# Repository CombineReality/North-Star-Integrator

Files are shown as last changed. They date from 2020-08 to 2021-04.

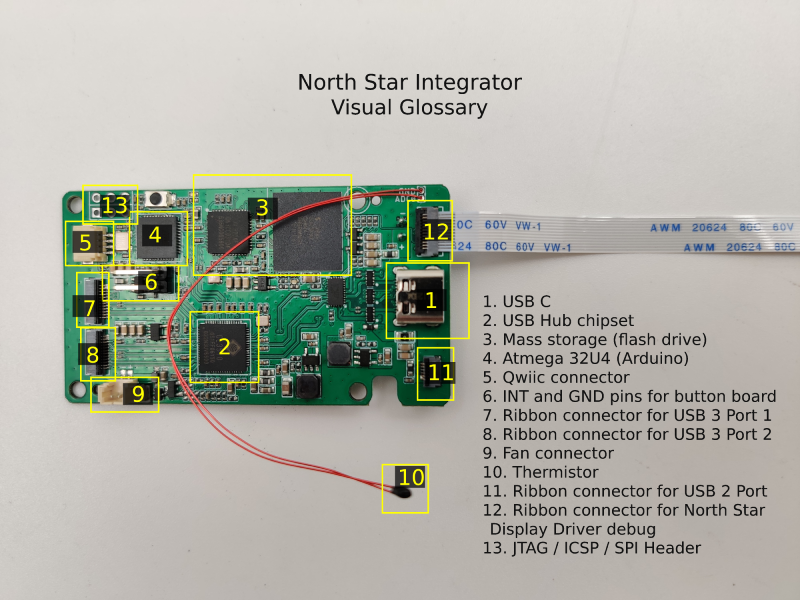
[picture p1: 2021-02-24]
docs/pcb_sections.png

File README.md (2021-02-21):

The Integrator is our custom-built USB hub system originally created for the CombineReality Project North Star Deck X. The Integrator cuts down the use of cables and adds customizable buttons to the headset with the following components & features:

    USB-C hub, two USB 3.1 ribbon connectors, and one USB 2.0 ribbon connector
    3GB on-board flash drive (only works when connected to a USB 3.0 host)
    Arduino-compatible microcontroller, featuring a Qwiic connector that can be used to connect additional sensors like an IMU, as well as HID buttons that can emulate keyboard    keys. A button breakout board is included, and the microcontroller is preflashed with firmware that maps the buttons to the default ergonomics adjustment keys. (Eye relief, eye position, and IPD)
    Also allows for manual power reset of sensor USB ports via a GPIO pin.
    A fan, the speed of which is controlled by the Arduino-compatible microcontroller.
    A thermistor for a more intelligent fan speed control
    A ribbon connector that lets the Arduino on the hub relay commands and debug output to and from the serial UART of the display driver board
    Ribbon adapter board for Intel® RealSense™ T261 embedded 6-DOF module (ribbon cable included)
    Ribbon adapter board for Leap Motion Controller (ribbon cable included)
    
Uses a modified version of the lilyPadUSB-caterina Arduino bootloader
Bootloader can be found here: https://github.com/CombineReality/ArduinoCore-avr

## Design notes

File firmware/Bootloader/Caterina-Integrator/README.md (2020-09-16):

# Arduino_USB_Bootloader
1. git clone 
2. sudo apt-get install gcc-avr binutils-avr gdb-avr avr-libc avrdude
3. cd ../bootloaders/caterina-LilyPadUSB
4. edit the code and makefile if necessary
5. make clean
6. make 
7. file the new HEX file of "Caterina.hex"

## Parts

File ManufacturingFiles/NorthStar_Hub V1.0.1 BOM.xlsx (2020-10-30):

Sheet: PCB SPECS (please fill in)
PCB
File Name/文件名 | Material/板材 | Layer/层数 | Dimension(mm)/尺寸 |  | Quantity/数量 | Separated Different Design/同个Gerber几款板子 | Panelized PCBs/是否拼版 | Solder Mask Color/阻焊颜色 | Silkscreen Color/丝印颜色 | PCB Thickness/板子厚度 | Copper Thickness/外层铜厚 | Inner Copper Thickness/内层铜厚 | Surface Finish/表面处理
 |  |  | X | Y |  |  |  |  |  | (mm) | (oz) | (oz)
NorthStar_Hub V1.0.1 Gerber.zip | FR-4 TG130 | 4 | 67 | 37 | 100 | 1 | Not Required | Green | White | 1 | 1 oz | 0.5 oz | HASL (Hot Air Surface Leveling)
SPECIAL REQUIREMENTS
Min. Tracking/Spacing/最小间距 | 4 mil
Min. Hole Size/最小孔径 | 0.20 mm
BGA/是否有BGA | Yes
Edge Connector/金手指 | No
Blind Vias/盲孔 | No
Half Cutted Holes/半孔 | No
Impedance Control/阻抗 | Yes | 嘉立创 JLC2313层压结构
STENCIL
Stencil Dimensions/钢网大小 | 140 x 240 mm (with frame)
Stencil Quantity/数量 | 1
Fiducial Mark/马克点 | Yes
Polishing Technique/钢网类型 | Polishing
REMARK
Please leave comment here if you have special requirements./特殊要求请备注
Our Smart-Prototyping website is for your reference. (http://smart-prototyping.com/PCB-Prototyping.html)

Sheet: BOM (please fill in)
Project Name (Required)/项目名字 |  | NorthStar
# | Part ID / Reference (Required)/位号 | Manufacturer/品牌 | Part Number (Required)/物料型号 | Description/物料描述 | Value (Required)/物料数值 | Package (Required)/物料封装 | THT (y/n)/直插为y，贴片为n | Pins / Pads Qty/管脚数量 | Quantity per BOM (Required)/用量
1 | C1, C21 | SAMSUNG | CL05C200JB5NNNC |  | 20pF ±5% 50V | C0402 |  |  | 2
2 | C25, C30, C71, C75, C78, C81, C82, C89, C99 | SAMSUNG | CL05A105KP5NNNC |  | 1uF ±10% 10V | C0402 |  |  | 9
3 | C3, C4, C5, C6, C7, C8, C15, C16, C41, C42, C43, C48, C69, C70 | SAMSUNG | CL03A104KP3NNNC |  | 100nF ±10% 10V | C0201 |  |  | 14
4 | C9, C56 | SAMSUNG | CL10A475KP8NNNC |  | 4.7uF ±10% 10V | C0603 |  |  | 2
5 | C10, C13, C17, C19, C22, C24, C33, C34, C35, C36, C37, C44, C52, C57, C59, C60, C61, C62, C63, C64, C65, C67, C68, C72, C79, C80, C84, C86, C88, C90, C91, C92, C93, C94, C95, C96, C97, C101, C104, C105, C106 | SAMSUNG | CL05B104KP5NNNC |  | 100nF ±10% 10V | C0402 |  |  | 41
6 | C11, C58 | SAMSUNG | CL05C560JB5NNNC |  | 56pF ±5% 50V | C0402 |  |  | 2
7 | C12, C49, C66, C100, C102, C103 | SAMSUNG | CL10A106MP8NNNC |  | 10uF ±10% 10V | C0603 |  |  | 6
8 | C14, C29 | SAMSUNG | CL21A226MPQNNNE |  | 22uF ±20% 10V | C0805 |  |  | 2
9 | C18, C20, C23, C26, C27, C28, C32, C38, C39, C45, C46, C47, C53, C54, C55 | SAMSUNG | CL10A226MP8NUNE |  | 22uF ±20% 10V | C0603 |  |  | 15
10 | C31, C85 | SAMSUNG | CL05C220JB5NNNC |  | 22pF ±5% 50V | C0402 |  |  | 2
11 | C40, C50, C73, C74, C83, C87, C98 | SAMSUNG | CL05A225MP5NNNC |  | 2.2uF ±10% 10V | C0402 |  |  | 7
12 | C76, C77 | SAMSUNG | CL05C120JB5NNNC |  | 12pF ±10% 50V | C0402 |  |  | 2
13 | D1, D2, D5 | TI | TPD4E05U06DQAR |  | TPD4E05U06DQAR | USON-10_L2.5-W1.0-P0.50-BL |  |  | 3
14 | D3, D6 | EVERLIGHT | 16-213/BHC-AN1P2/3T |  | BLUE | 0402_LED |  |  | 2
15 | D4 | 安森美 | ESD5Z6.0T1G |  | ESD5Z6.0T1G | SOD523 |  |  | 1
16 | H1 | TOSHIBA(东芝) | THGBMNG5D1LBAIL |  | THGBMNG5D1LBAIL | BGA153C50P14X14_11.5X13 |  |  | 1
17 | IC1 | GENESYS(创惟) | GL3510-OSY50 |  | GL3510-OSY50 | QFN40P800X800X80-65N |  |  | 1
18 | IC2 | MICROCHIP | ATMEGA32U4-MUR |  | ATMEGA32U4-MUR | QFN50P700X700X100-45N |  |  | 1
19 | J1 | HRS | FH34SRJ-6S-0.5SH(50) |  | FH34SRJ-6S-0.5SH(50) | FH34RJ-6S |  |  | 1
20 | J3, J8, J9 | HRS | FH34SRJ-12S-0.5SH(50) |  | FH34SRJ-12S-0.5SH(50) | FPC-0.5-12P |  |  | 3
21 | J4 | BOOMELE(博穆精密) | XH-2AW |  | XH-2AW | XH-02-90 |  |  | 1
22 | J6 | JST | SM04B-SRSS-TB(LF)(SN) |  | SM04B-SRSS-TB(LF)(SN) | SM04B-SRSS-TB |  |  | 1
23 | K1 | ALPS | SKRKAEE020 |  | SKRKAEE020 | SKRKAEE020 |  |  | 1
24 | L1, L10 | SXN(顺翔诺) | SMNR4012-2R2MT |  | SMNR4012-2R2MT | L4012 |  |  | 2
25 | L2, L3, L4, L5, L6, L7, L8, L9 | muRata | BLM18EG221SN1D |  | BLM18EG221SN1D | L0603 |  |  | 8
26 | R1, R17, R33, R35, R40, R43, R44, R45 | UNI-ROYAL(厚声) | 0402WGF1002TCE |  | 10K ±1% | R0402 |  |  | 8
27 | R2 | UNI-ROYAL(厚声) | 0402WGF4702TCE |  | 47K ±1% | R0402 |  |  | 1
28 | R3, R26 | UNI-ROYAL(厚声) | 0402WGF1004TCE |  | 1M ±1% | R0402 |  |  | 2
29 | R22 | UNI-ROYAL(厚声) | 0402WGF6800TCE |  | 680R ±1% | R0402 |  |  | 1
30 | R5 | UNI-ROYAL(厚声) | 0805W8F0000T5E |  | 0R ±1% | R0805 |  |  | 1
31 | R6, R9, R36, R39 | UNI-ROYAL(厚声) | 0402WGF1003TCE |  | 100K ±1% | R0402 |  |  | 4
32 | R7, R37 | UNI-ROYAL(厚声) | 0402WGF3604TCE |  | 3.6M ±1% | R0402 |  |  | 2
33 | R12 | UNI-ROYAL(厚声) | 0402WGF4703TCE |  | 470K ±1% | R0402 |  |  | 1
34 | R13 | UNI-ROYAL(厚声) | 0402WGF1073TCE |  | 107K ±1% | R0402 |  |  | 1
35 | R15, R27, R30, R47, R48, R49, R50, R51 | UNI-ROYAL(厚声) | 0402WGF4701TCE |  | 4.7K ±1% | R0402 |  |  | 8
36 | R16, R18, R19 | UNI-ROYAL(厚声) | 0402WGF2003TCE |  | 200K ±1% | R0402 |  |  | 3
37 | R20 | UNI-ROYAL(厚声) | 0402WGF9093TCE |  | 909K ±1% | R0402 |  |  | 1
38 | R21, R38, R41, R42, R46 | UNI-ROYAL(厚声) | 0402WGF0000TCE |  | 0R ±1% | R0402 |  |  | 5
39 | R23, R32 | UNI-ROYAL(厚声) | 0402WGF2001TCE |  | 2K ±1% | R0402 |  |  | 2
40 | R24 | UNI-ROYAL(厚声) | 0402WGF470JTCE |  | 47R ±1% | R0402 |  |  | 1
41 | R25, R34 | UNI-ROYAL(厚声) | 0402WGF5102TCE |  | 51K ±1% | R0402 |  |  | 2
42 | R28, R29 | UNI-ROYAL(厚声) | 0402WGF220JTCE |  | 22R ±1% | R0402 |  |  | 2
43 | R31 | UNI-ROYAL(厚声) | 0402WGF2200TCE |  | 220R ±1% | R0402 |  |  | 1
44 | U2 | TI | HD3SS3220RNHR |  | HD3SS3220RNHR | RNH0030A |  |  | 1
45 | U3 | GENESYS(创惟) | GL3224E-ONY04 |  | GL3224E-ONY04 | TQFN48_7MM |  |  | 1
46 | U4, U5 | 矽力杰silergy | SY8089AAAC |  | SY8089AAAC | SOT23-5 |  |  | 2
47 | U6, U7, U8 | TI | TPS2065CDBVR |  | TPS2065C | SOT23-5 |  |  | 3
48 | USBC1 | MOLEX | 1054500101 |  | 1054500101 | USB-C-SMD_TYPE-C-USB-18 |  |  | 1
49 | X1 | EPSON(爱普生) | X1E000021011900 |  | X1E000021011900 | 4P-SMD-3.2X2.5 |  |  | 1
50 | X3, X4 | EPSON(爱普生) | Q22FA12800388 |  | Q22FA12800388 | 4P-SMD-2X1.6MM |  |  | 2
51 | FPC排线0.5mm 12P 同向 |  |  | FPC软排线 间距 0.5mm 12P 同向A型 8cm |  |  |  |  | 2
52 | FPC排线0.5mm 6P 同向 |  |  | FPC软排线 间距 0.5mm 6P 同向A型 8cm |  |  |  |  | 1
53 | D7 | Nexperia(安世) | PMEG2010EA,115 |  | PMEG2010EA,115 | SOD323 |  |  | 1
54 | J5 | 533980271 | 533980271 |  | MX1.25-2P-90 | MX1.25-2P-90 |  |  | 1
55 | Q1 | CJ江苏长电(授权代理) | CJ2301 S1 |  | CJ2301 S1 | SOT23 |  |  | 1
56 | Q2 | CJ江苏长电(授权代理) | DTC143ZUA |  | DTC143ZUA | SOT323 |  |  | 1
57 | RT1 | 时恒 | MF52B 103F3950-100mm | 绝缘红色漆包引线,线长100mm | MF52B 103F3950-100mm |  |  |  | 1
58 | J7 |  |  | 2.54MM 单排正弯针 1*2P PA6.0 |  | 2P-2.54-65/35MIL
59 | Q3, Q4 | CJ江苏长电(授权代理) | BSS138W |  | BSS138W | SOT-323 |  |  | 2
60 | R4 | UNI-ROYAL(厚声) | 0402WGF2002TCE |  | 20K ±1% | R0402 |  |  | 1

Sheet: BOM Reference
BOM/PCBA quantity (Required) |  | 10
PCB/Project Name (Required) |  | Main Control V1.0
# | Part ID / Reference (Required) | Manufacturer | Part Number (Required) | Description | Value (Required) | Package (Required) | THT (y/n) | Pins / Pads Qty | Quantity per BOM (Required)
1 | C1, C2, C3, C4, C5, C7, C8, C9, C10, C11, C12, C13, C14, C15, C16, C17 | Samsung | CL10B104KB8NNNC | Capacitor SMD Cer 100nF 10% 50V X7R 0603 | 100nF | 0603 | n | 2 | 16
2 | R1, R2 | KOA | RK73H1ETTP1001F | 1KΩ (1001) ±1% |  | 0402 | n | 2 | 2
3 | U1 | MICROCHIP | ATMEGA88PA-AU | IC MCU 8BIT 8KB FLASH 32TQFP |  | 32TQFP | n | 32 | 1
4 | D3, D4, D5 | Kingbright | APT1608SURCK | LED 0603 SMD Hyper Red 630nm 220mcd 20mA |  |  | n | 2 | 4
5 | D1 | Lite-On Inc | LTL-4231N | Trigger LED |  |  | y | 2 | 1

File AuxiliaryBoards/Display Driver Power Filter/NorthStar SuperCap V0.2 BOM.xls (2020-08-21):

# | Part ID/Reference | Manufacturer | Part Number | Description | Value | Package | THT | Pins/Pads Qty | Source/Link/Datasheet/Note | Quantity/per BOM | NOTE
 | C1 | KORCHIP | DCS5R5104 |  | DCS5R5104 | 11.5X5.5MM-P10 H-TYPE |  |  |  | 1 |  | 2.11
 | C2 | Rubycon | 10YXF470MEFCT78X11.5 |  | 10YXF470MEFCT78X11.5 | ELECTRO-8.0MM |  |  |  | 1 |  | 0.334787
 | J2 |  |  | 单排错列蜈蚣脚排母2P 间距2.54 塑高5mm 左前右后 |  | 2P-2.54-BOTTOM-ENTRY |  |  | https://item.taobao.com/item.htm?spm=a1z09.2.0.0.67002e8d9SZdHa&id=548294171308&_u=21o068jo1c38 | 1 |  | 0.5
 | XH-2P 线 |  |  | XH2.54-2P 端子线 单头上锡 5CM 左红右黑 |  |  |  |  | https://item.taobao.com/item.htm?id=551594001350&ns=1&abbucket=12 (https://item.taobao.com/item.htm?spm=a230r.1.14.16.665015daMGJz8G&id=551594001350&ns=1&abbucket=12) | 1

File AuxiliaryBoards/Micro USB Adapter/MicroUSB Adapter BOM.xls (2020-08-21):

# | Part ID/Reference | Manufacturer | Part Number | Description | Value | Package | THT | Pins/Pads Qty | Source/Link/Datasheet/Note | Quantity/per BOM | NOTE
 | J1 | HRS | FH34SRJ-6S-0.5SH(50) |  | FPC-0.5-6P | FH34RJ-6S |  |  |  | 1 |  | 0.37208
 | J2 | 韩国韩荣 | U-G-M5WS-W-01 |  | MICRO_USB_MALEU-G-M5WS-W-01 | U-G-M5WS-W-01 |  |  |  | 1 |  | 0.603

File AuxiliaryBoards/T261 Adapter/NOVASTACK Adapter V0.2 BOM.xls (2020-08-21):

# | Part ID/Reference | Manufacturer | Part Number | Description | Value | Package | THT | Pins/Pads Qty | Source/Link/Datasheet/Note | Quantity/per BOM | NOTE
 | D4 | 安森美 | ESD5Z6.0T1G |  | ESD5Z6.0T1G | SOD523 |  |  |  | 1 |  | 0.183493
 | J1 | HRS | FH34SRJ-12S-0.5SH(50) |  | FPC-0.5-12PFPC-0.5-12P | FPC-0.5-12P |  |  |  | 1 |  | 0.53
 | J2 | I-PEX | 20709-034E-01 |  | 20709-034E-01 | IPEX_20709-034E-01 |  |  |  | 1 | https://item.taobao.com/item.htm?spm=a1z09.2.0.0.7c7c2e8d4lBHUf&id=606906908072&_u=21o068jo1c7e | 5

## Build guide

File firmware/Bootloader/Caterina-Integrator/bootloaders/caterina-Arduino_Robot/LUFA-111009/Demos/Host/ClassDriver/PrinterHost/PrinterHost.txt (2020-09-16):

/** \file
 *
 *  This file contains special DoxyGen information for the generation of the main page and other special
 *  documentation pages. It is not a project source file.
 */

/** \mainpage Printer Host Demo
 *
 *  \section Sec_Compat Demo Compatibility:
 *
 *  The following list indicates what microcontrollers are compatible with this demo.
 *
 *  - Series 7 USB AVRs (AT90USBxxx7)
 *
 *  \section Sec_Info USB Information:
 *
 *  The following table gives a rundown of the USB utilization of this demo.
 *
 *  <table>
 *   <tr>
 *    <td><b>USB Mode:</b></td>
 *    <td>Host</td>
 *   </tr>
 *   <tr>
 *    <td><b>USB Class:</b></td>
 *    <td>Printer Device</td>
 *   </tr>
 *   <tr>
 *    <td><b>USB Subclass:</b></td>
 *    <td>Bidirectional Protocol</td>
 *   </tr>
 *   <tr>
 *    <td><b>Relevant Standards:</b></td>
 *    <td>USBIF Printer Class Specification \n
 *        PCL Language Specification</td>
 *   </tr>
 *   <tr>
 *    <td><b>Usable Speeds:</b></td>
 *    <td>Low Speed Mode \n
 *        Full Speed Mode</td>
 *   </tr>
 *  </table>
 *
 *  \section Sec_Description Project Description:
 *
 *  Printer host demonstration application. This gives a simple reference
 *  application for implementing a USB Printer host, for USB printers using
 *  the bidirectional data encapsulation protocol and PCL language.
 *
 *  Upon connection of a compatible printer, the printer's device ID is sent
 *  to the AVR's serial port, and a simple test page is printed using the PCL
 *  printer language.
 *
 *  \section Sec_Options Project Options
 *
 *  The following defines can be found in this demo, which can control the demo behaviour when defined, or changed in value.
 *
 *  <table>
 *   <tr>
 *    <td>
 *     None
 *    </td>
 *   </tr>
 *  </table>
 */

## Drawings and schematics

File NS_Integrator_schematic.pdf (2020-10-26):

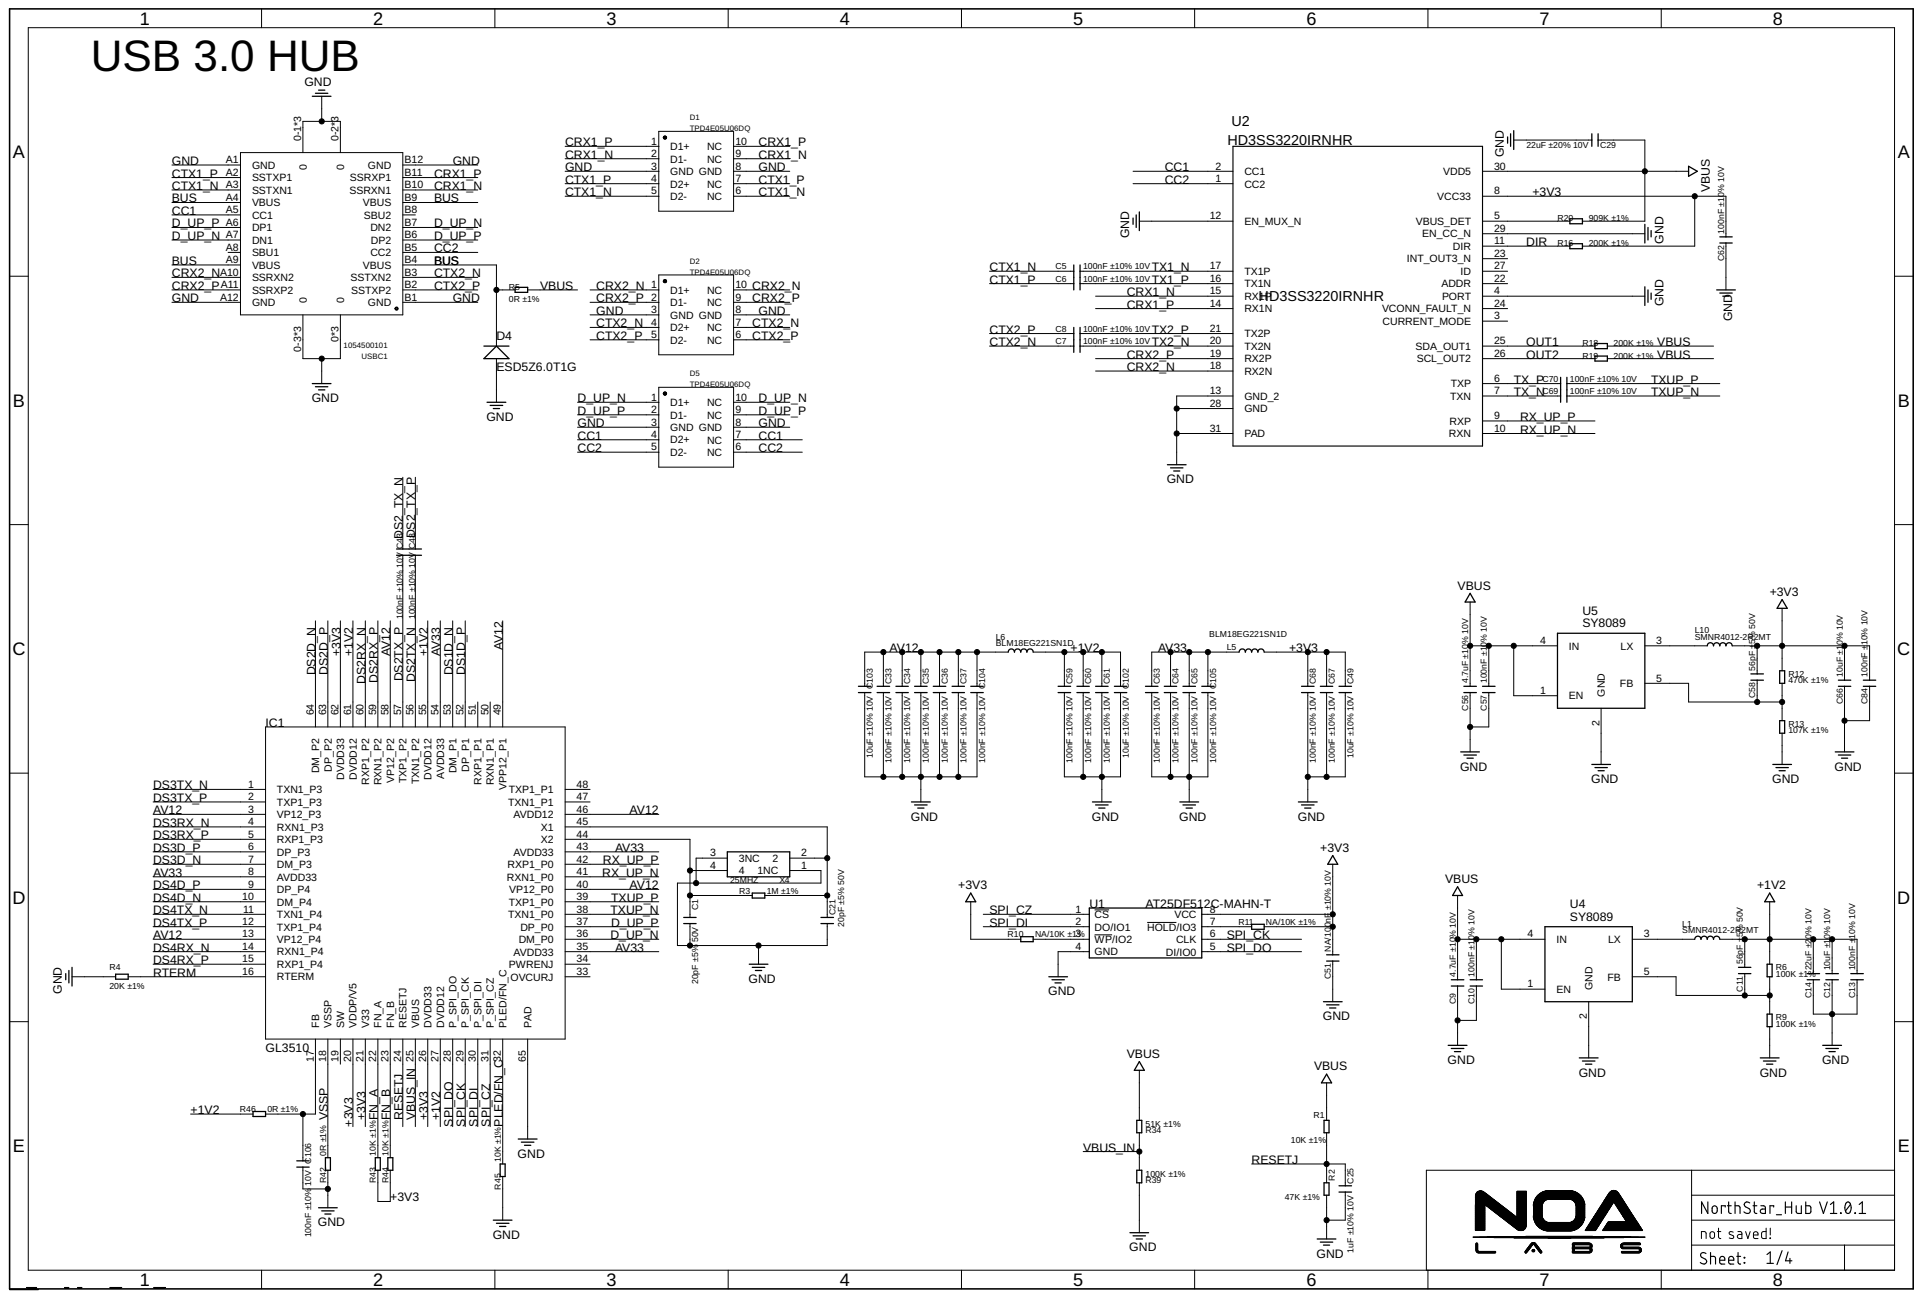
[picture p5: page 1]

39 VP12_P0 TXUP_P | 1M ±1%

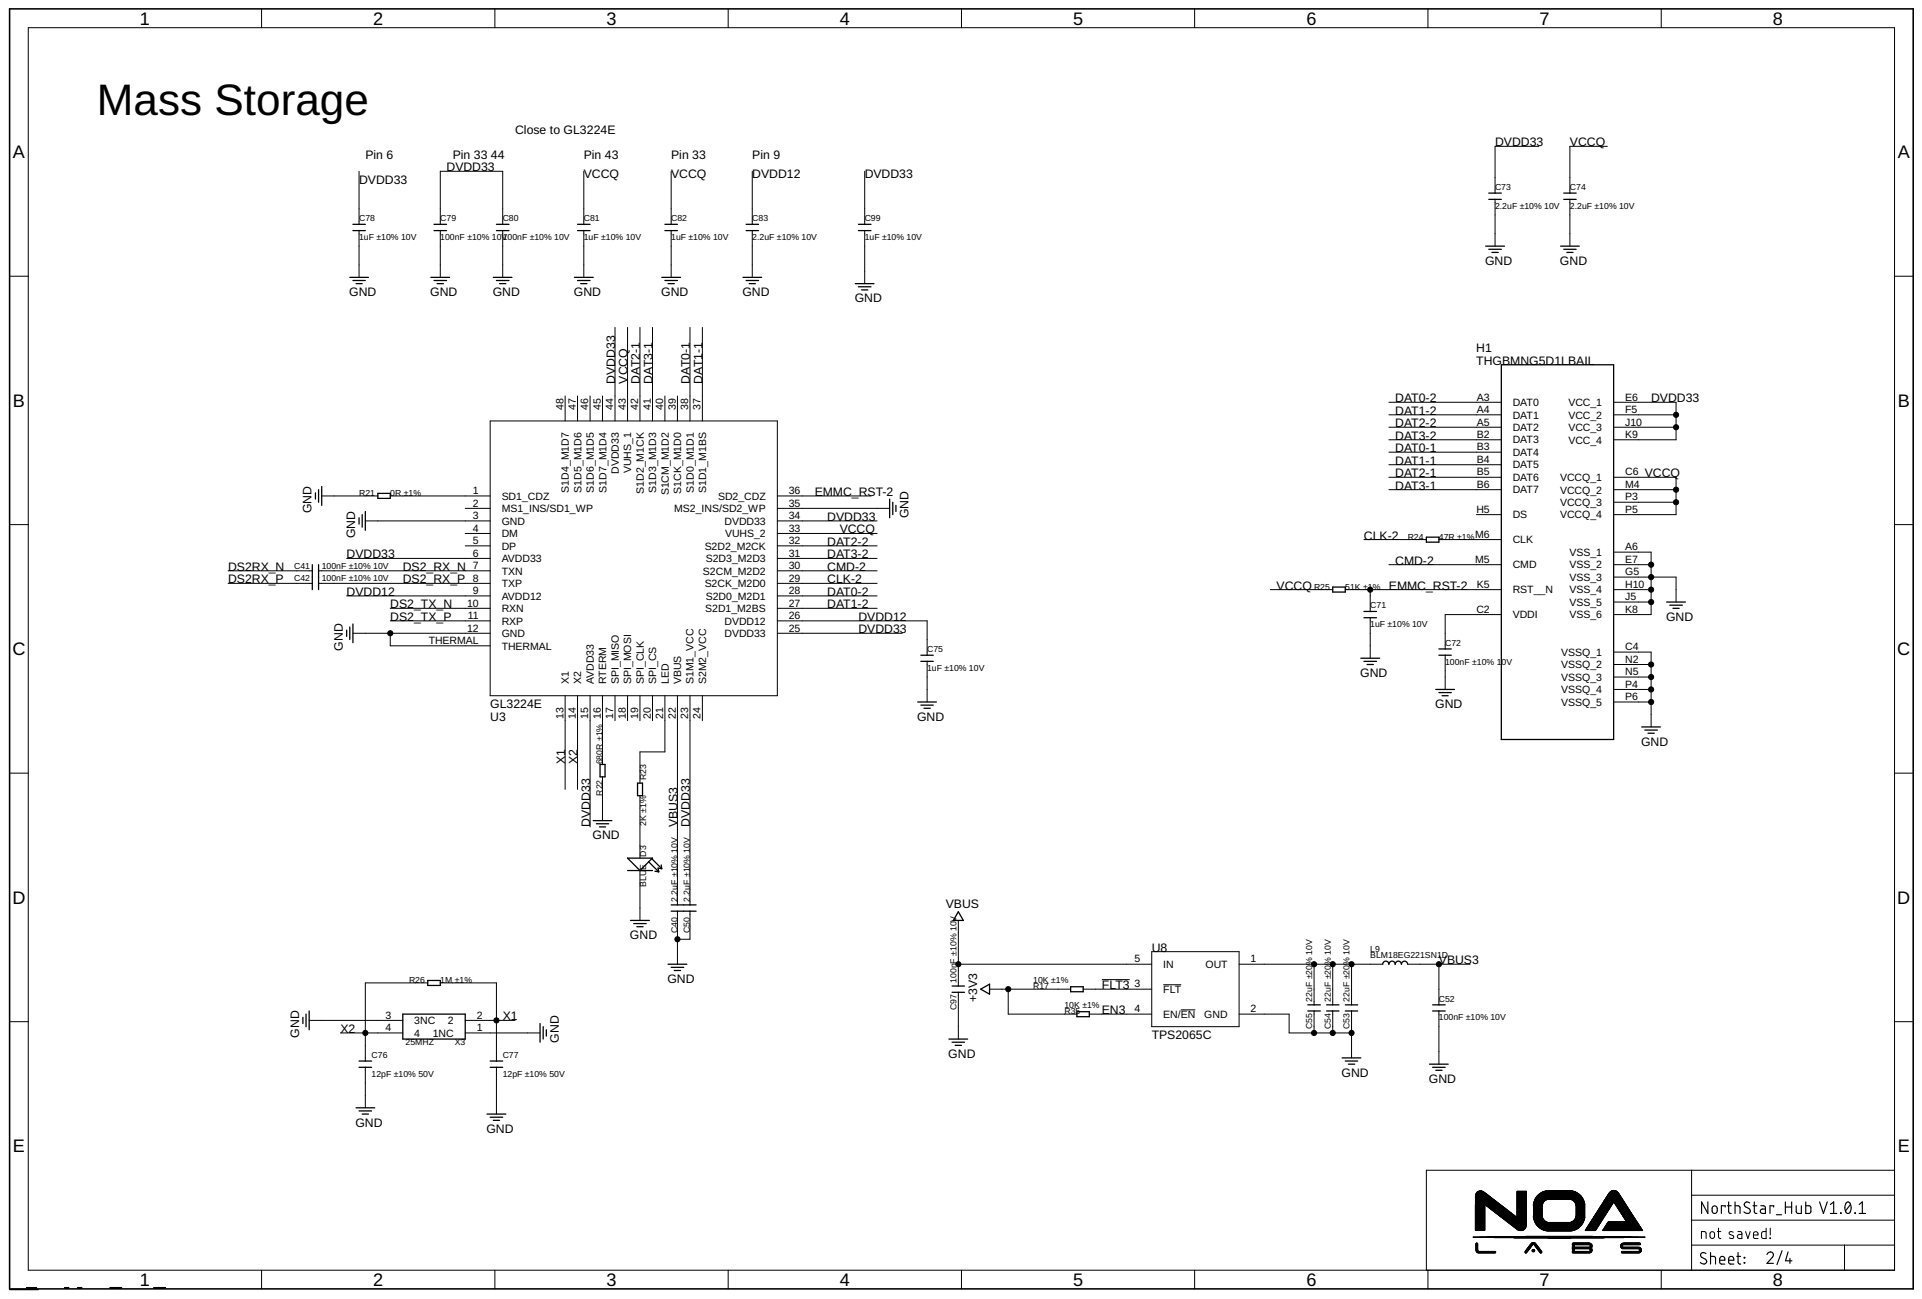
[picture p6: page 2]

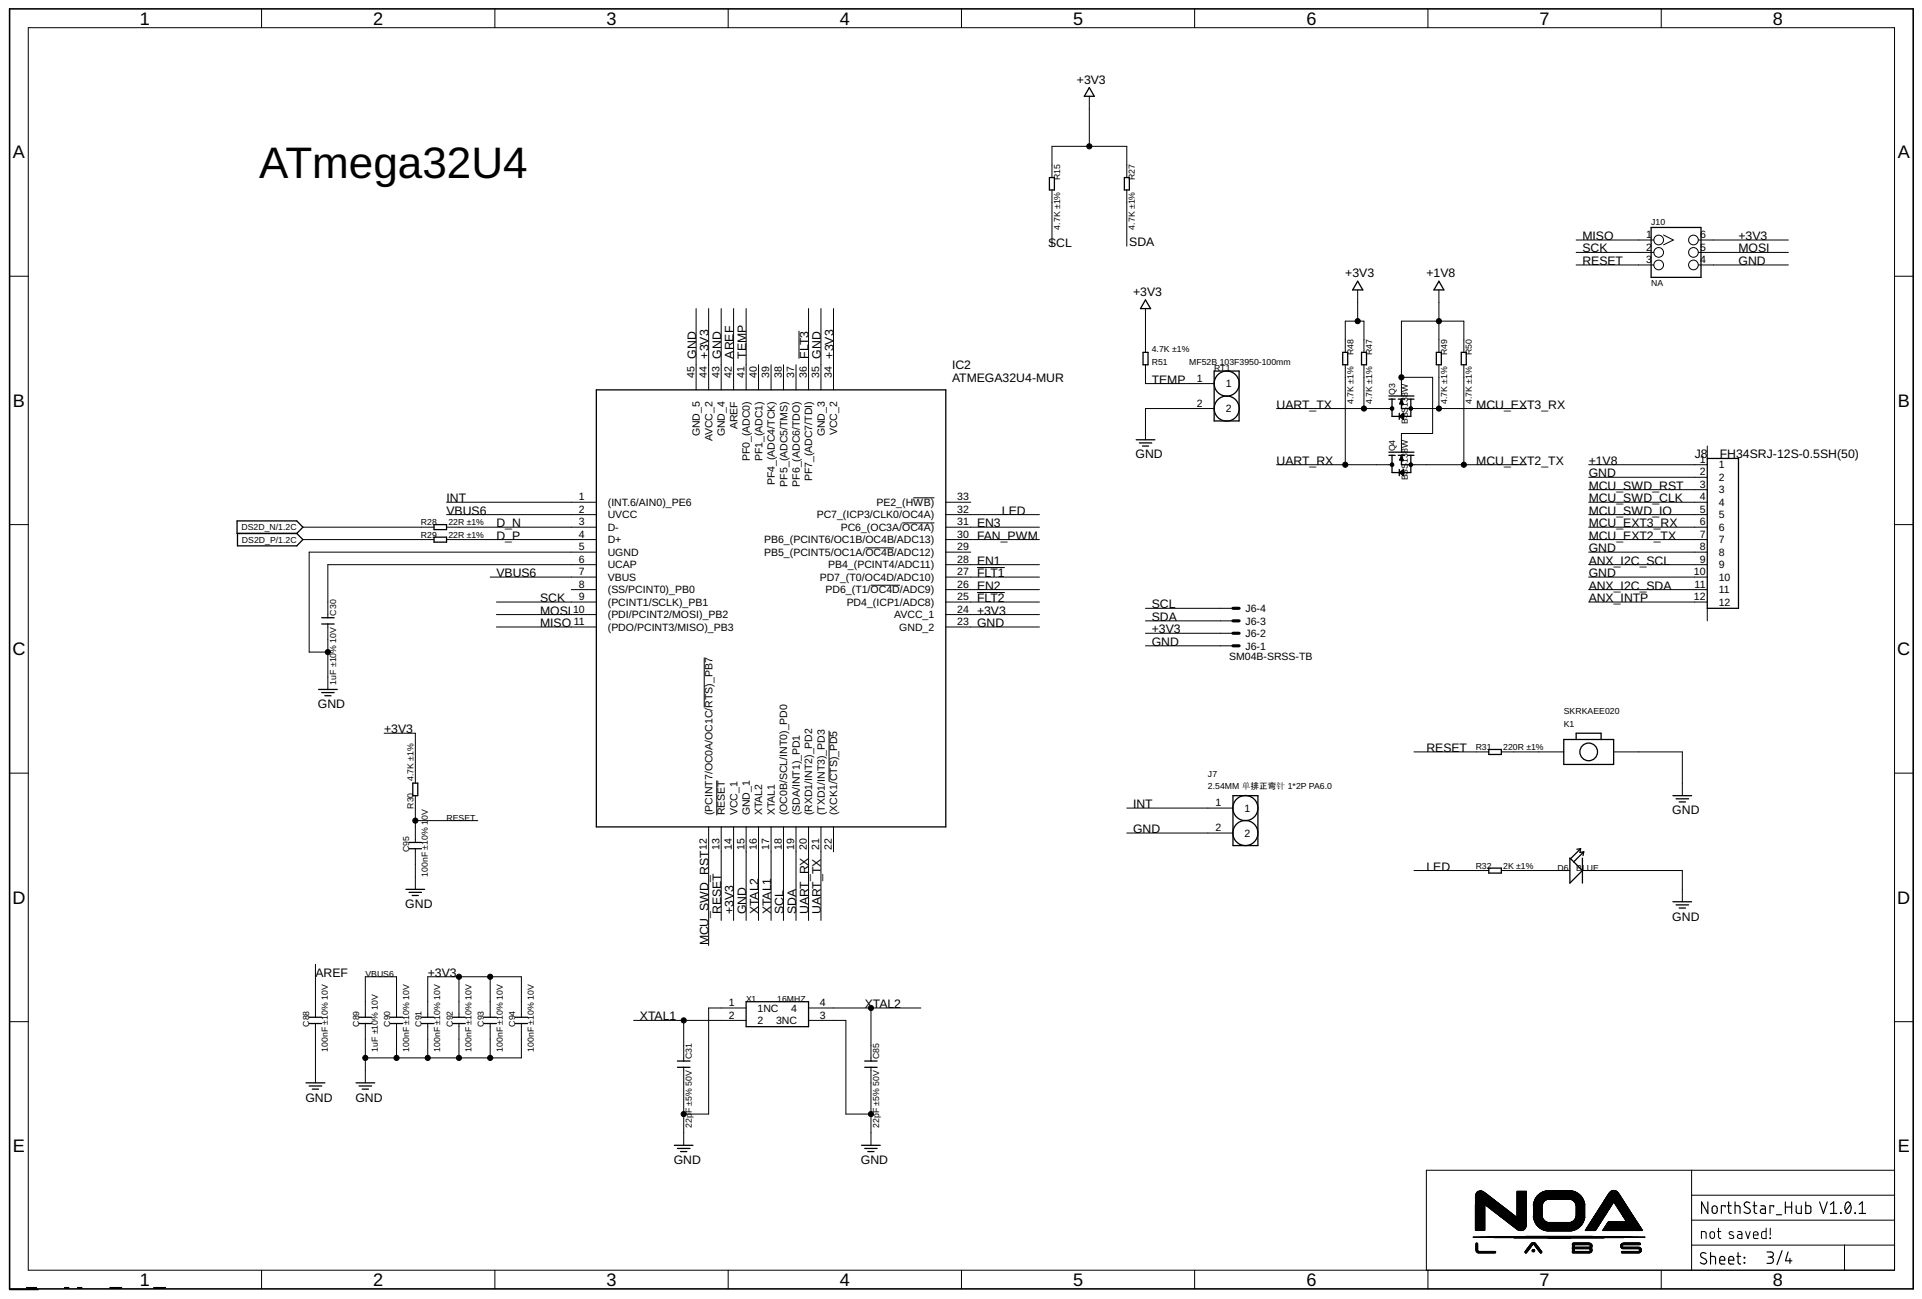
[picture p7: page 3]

GND GND

42 PF0_(ADC0) 41 PF1_(ADC1) 40 PF4_(ADC4/TCK) 39 PF5_(ADC5/TMS) 38 PF6_(ADC6/TDO) 37 PF7_(ADC7/TDI) 36 GND_3

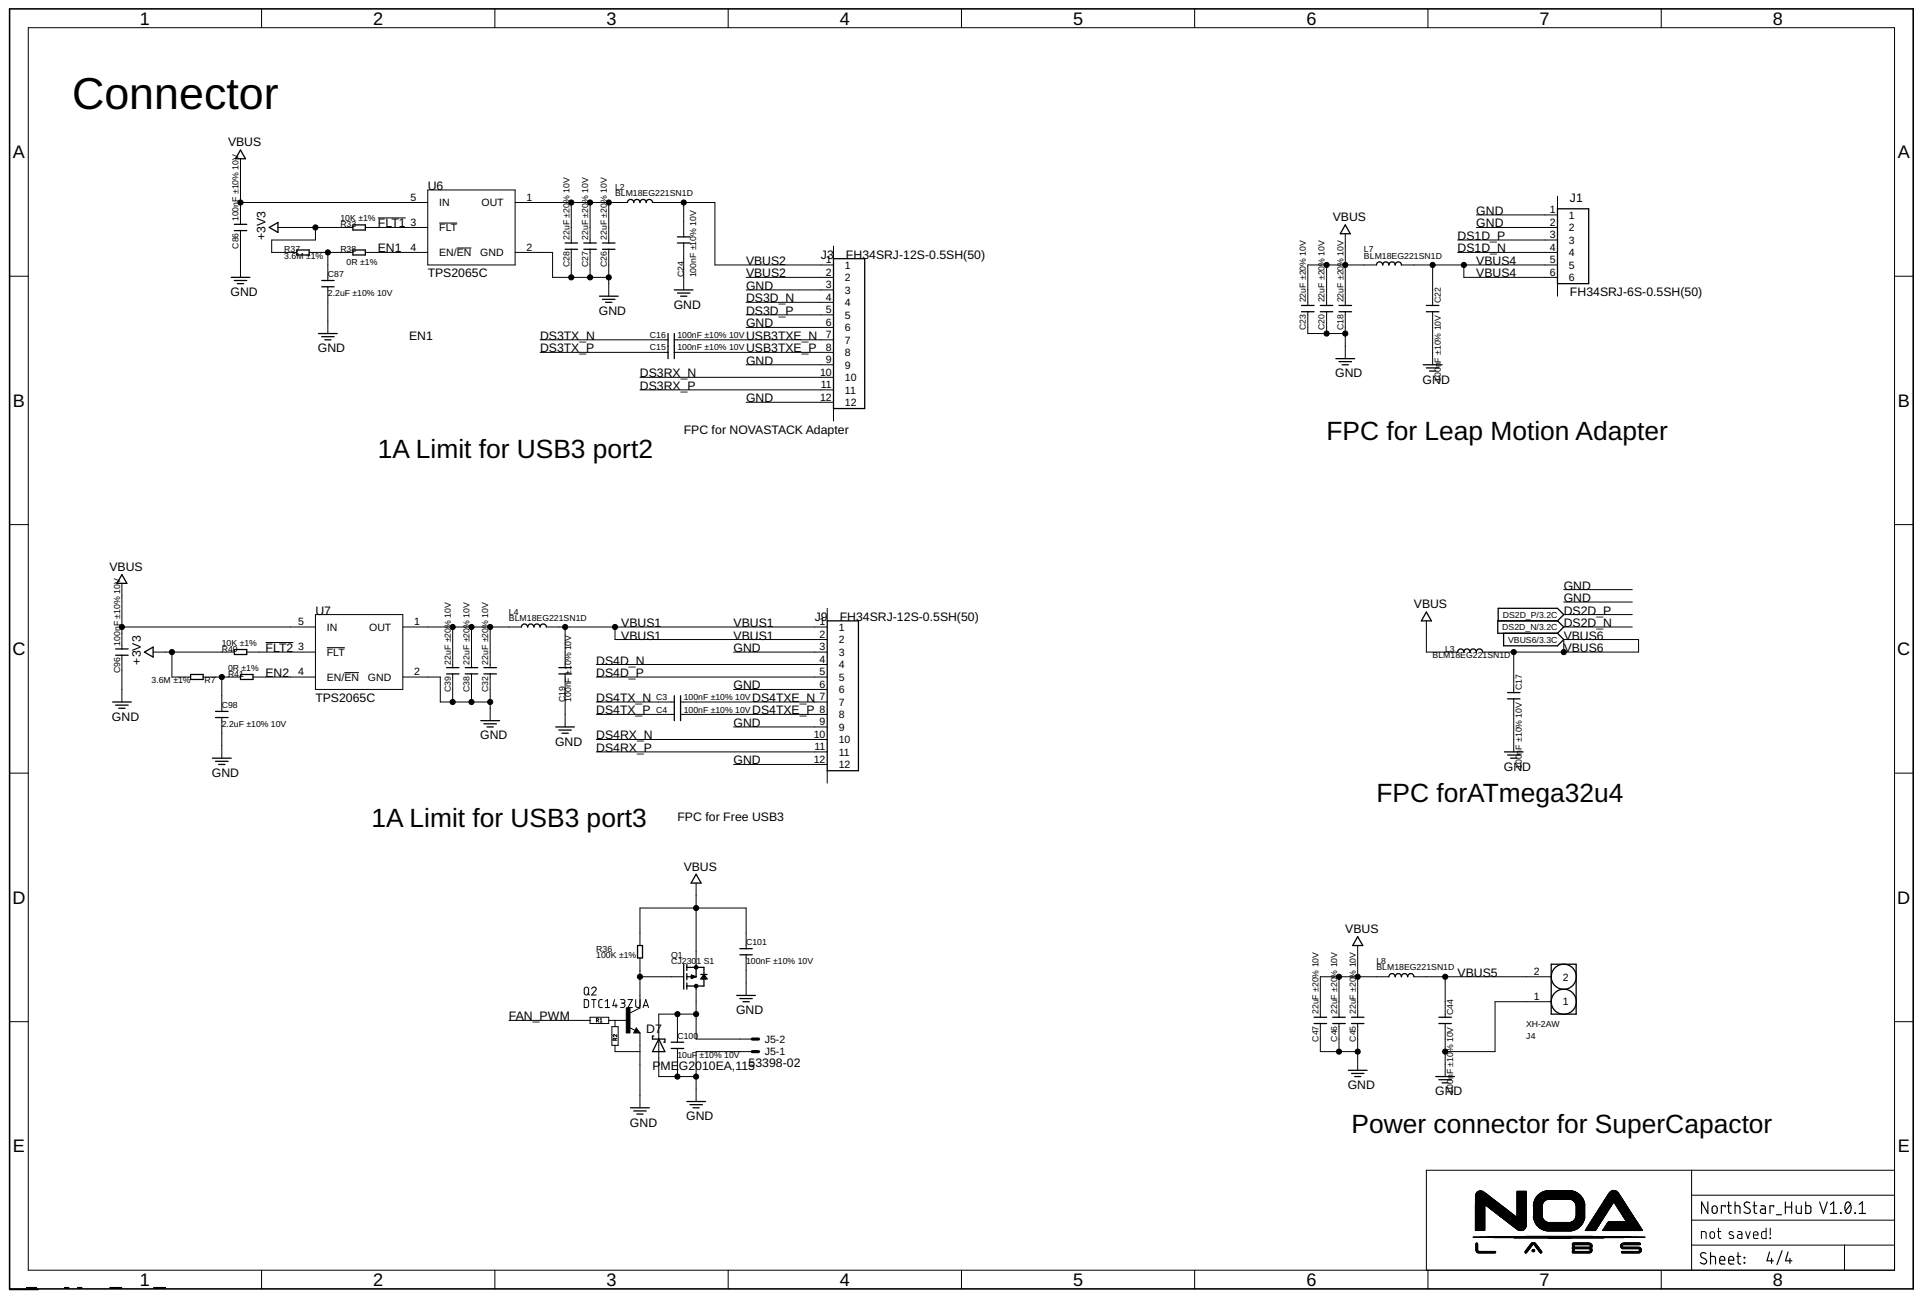
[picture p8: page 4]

FPC for NOVASTACK Adapter

FPC for Leap Motion Adapter

GND GND

GND
Power connector for SuperCapactor

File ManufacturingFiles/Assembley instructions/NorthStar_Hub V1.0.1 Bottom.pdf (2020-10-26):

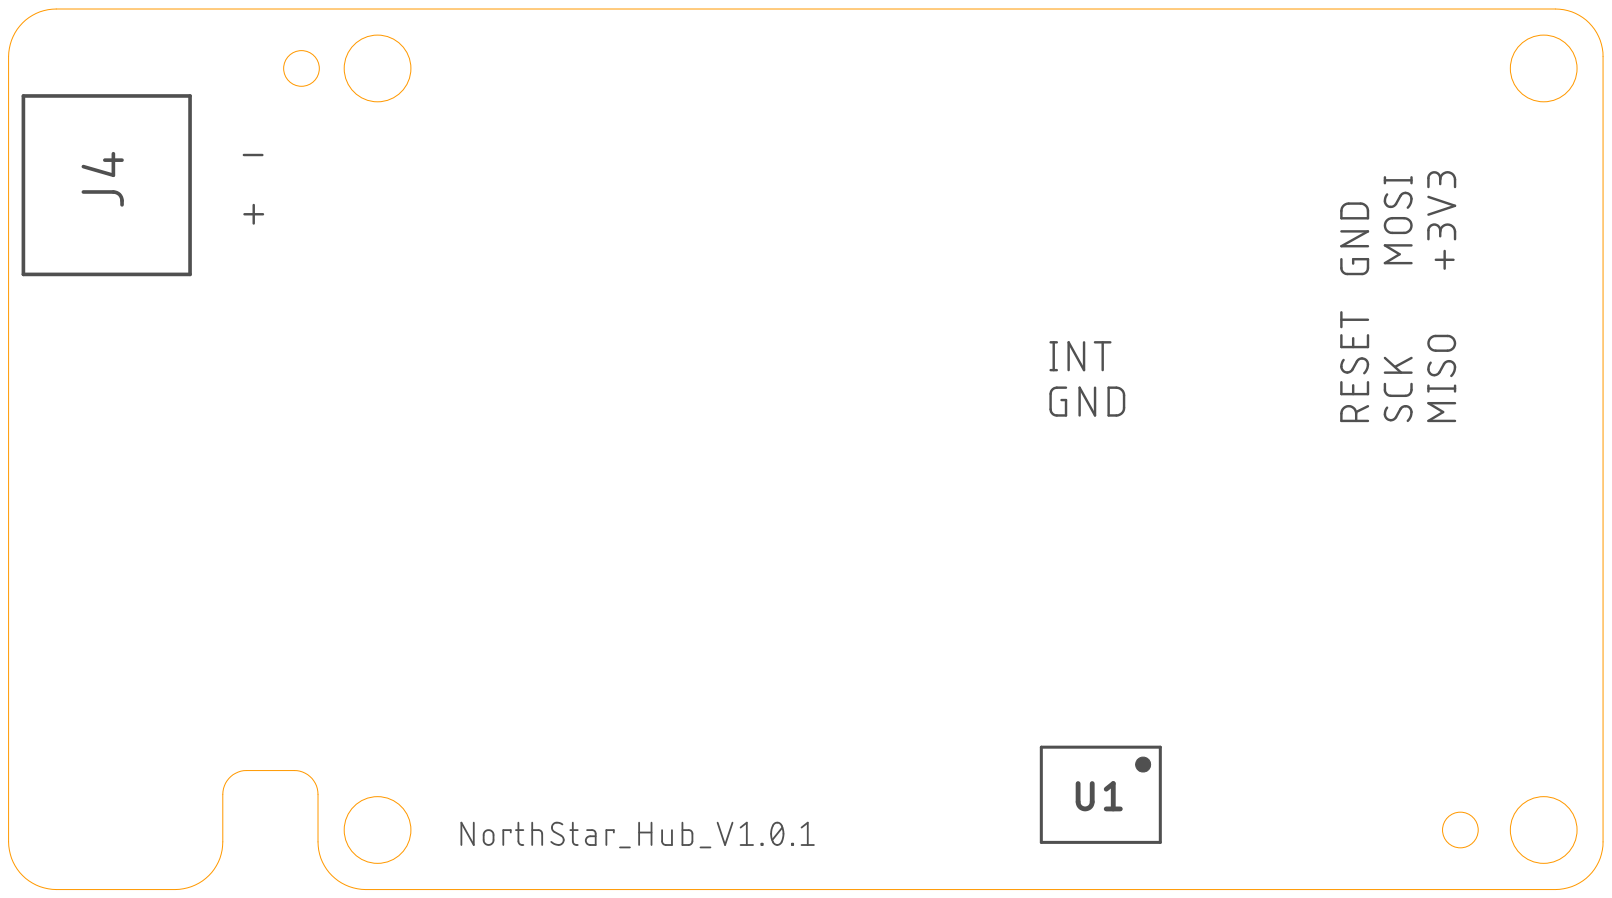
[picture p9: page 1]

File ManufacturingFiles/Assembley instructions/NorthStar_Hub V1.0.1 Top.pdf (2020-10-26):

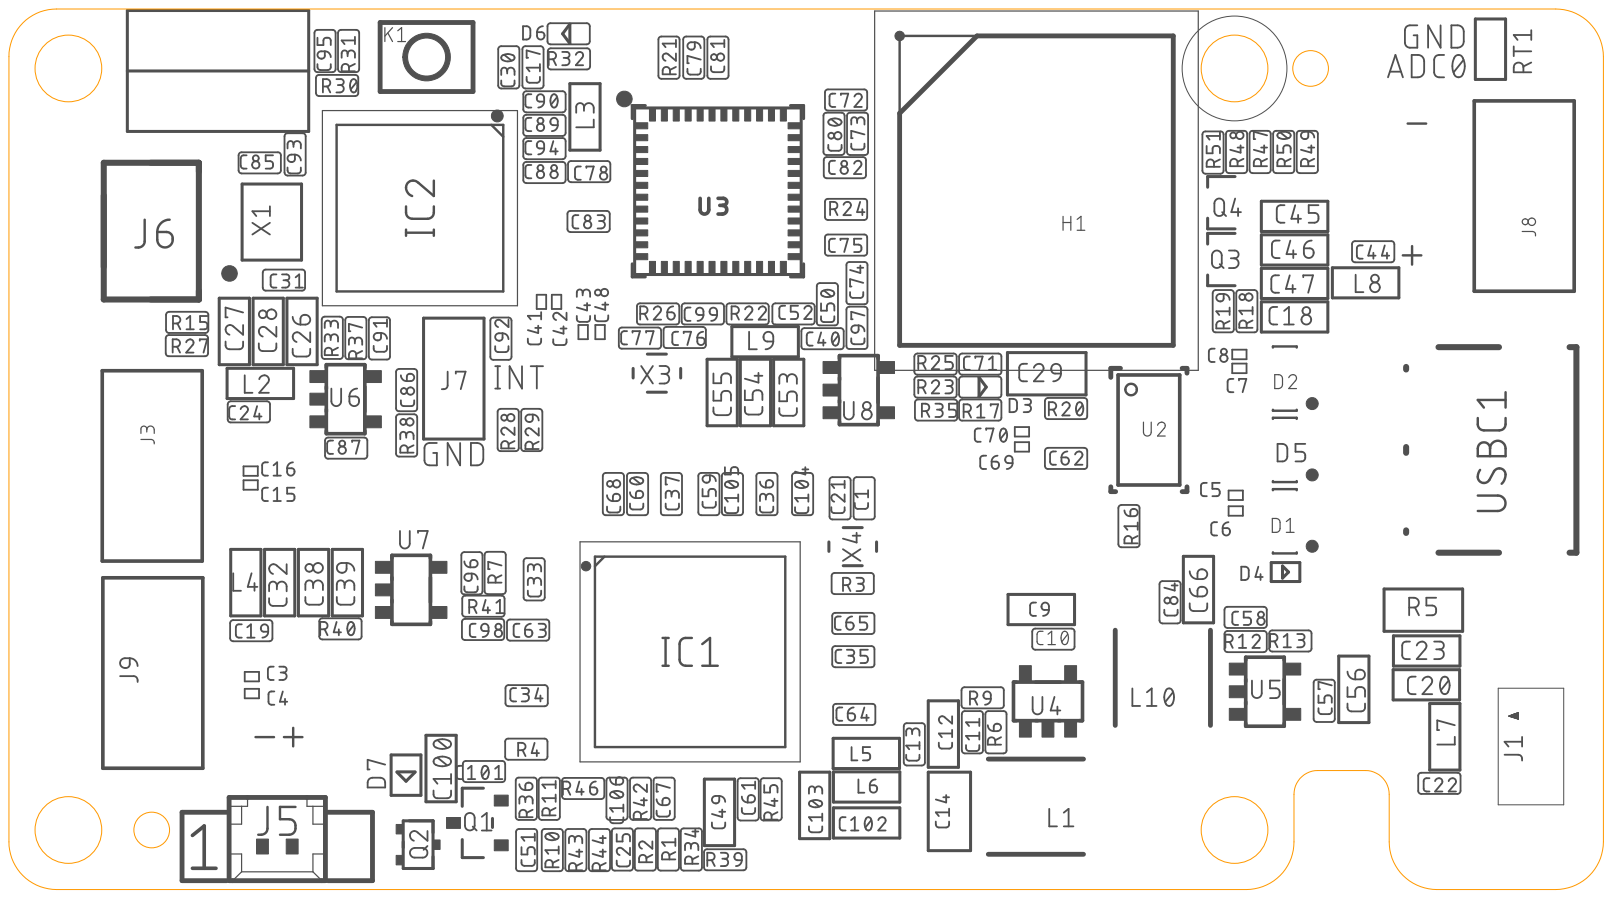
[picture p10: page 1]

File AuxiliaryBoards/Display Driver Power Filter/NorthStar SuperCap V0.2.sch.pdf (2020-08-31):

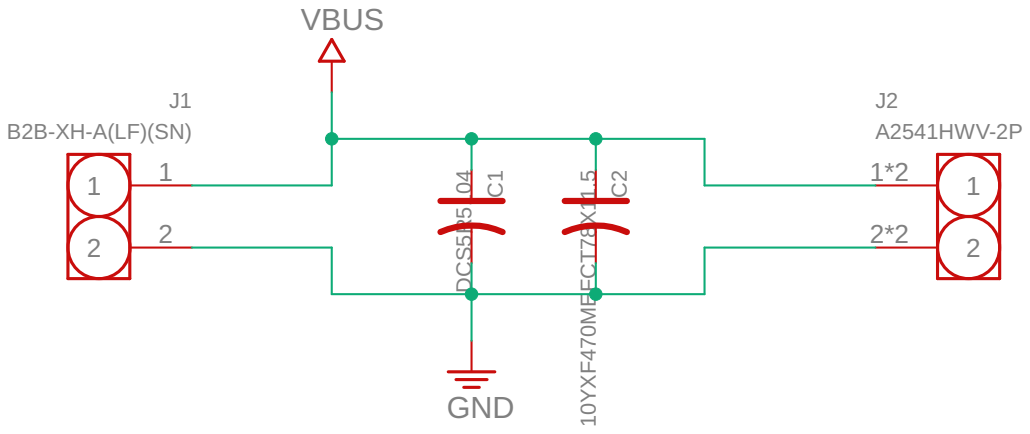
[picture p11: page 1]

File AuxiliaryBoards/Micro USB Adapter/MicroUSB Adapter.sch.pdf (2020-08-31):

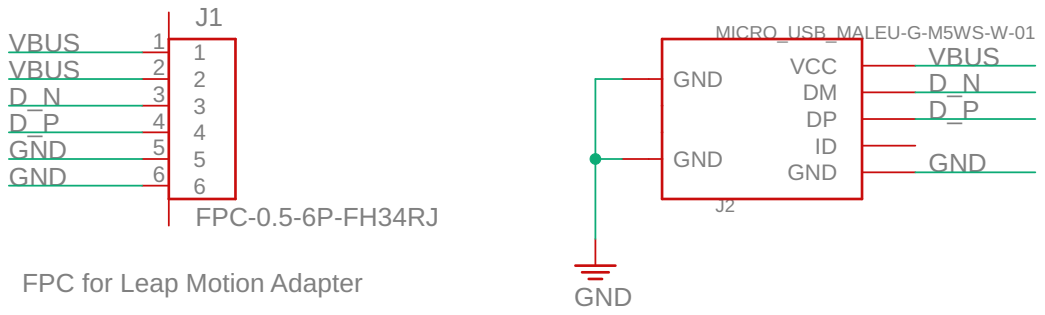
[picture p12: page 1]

FPC for Leap Motion Adapter FPC-0.5-6P-FH34RJ

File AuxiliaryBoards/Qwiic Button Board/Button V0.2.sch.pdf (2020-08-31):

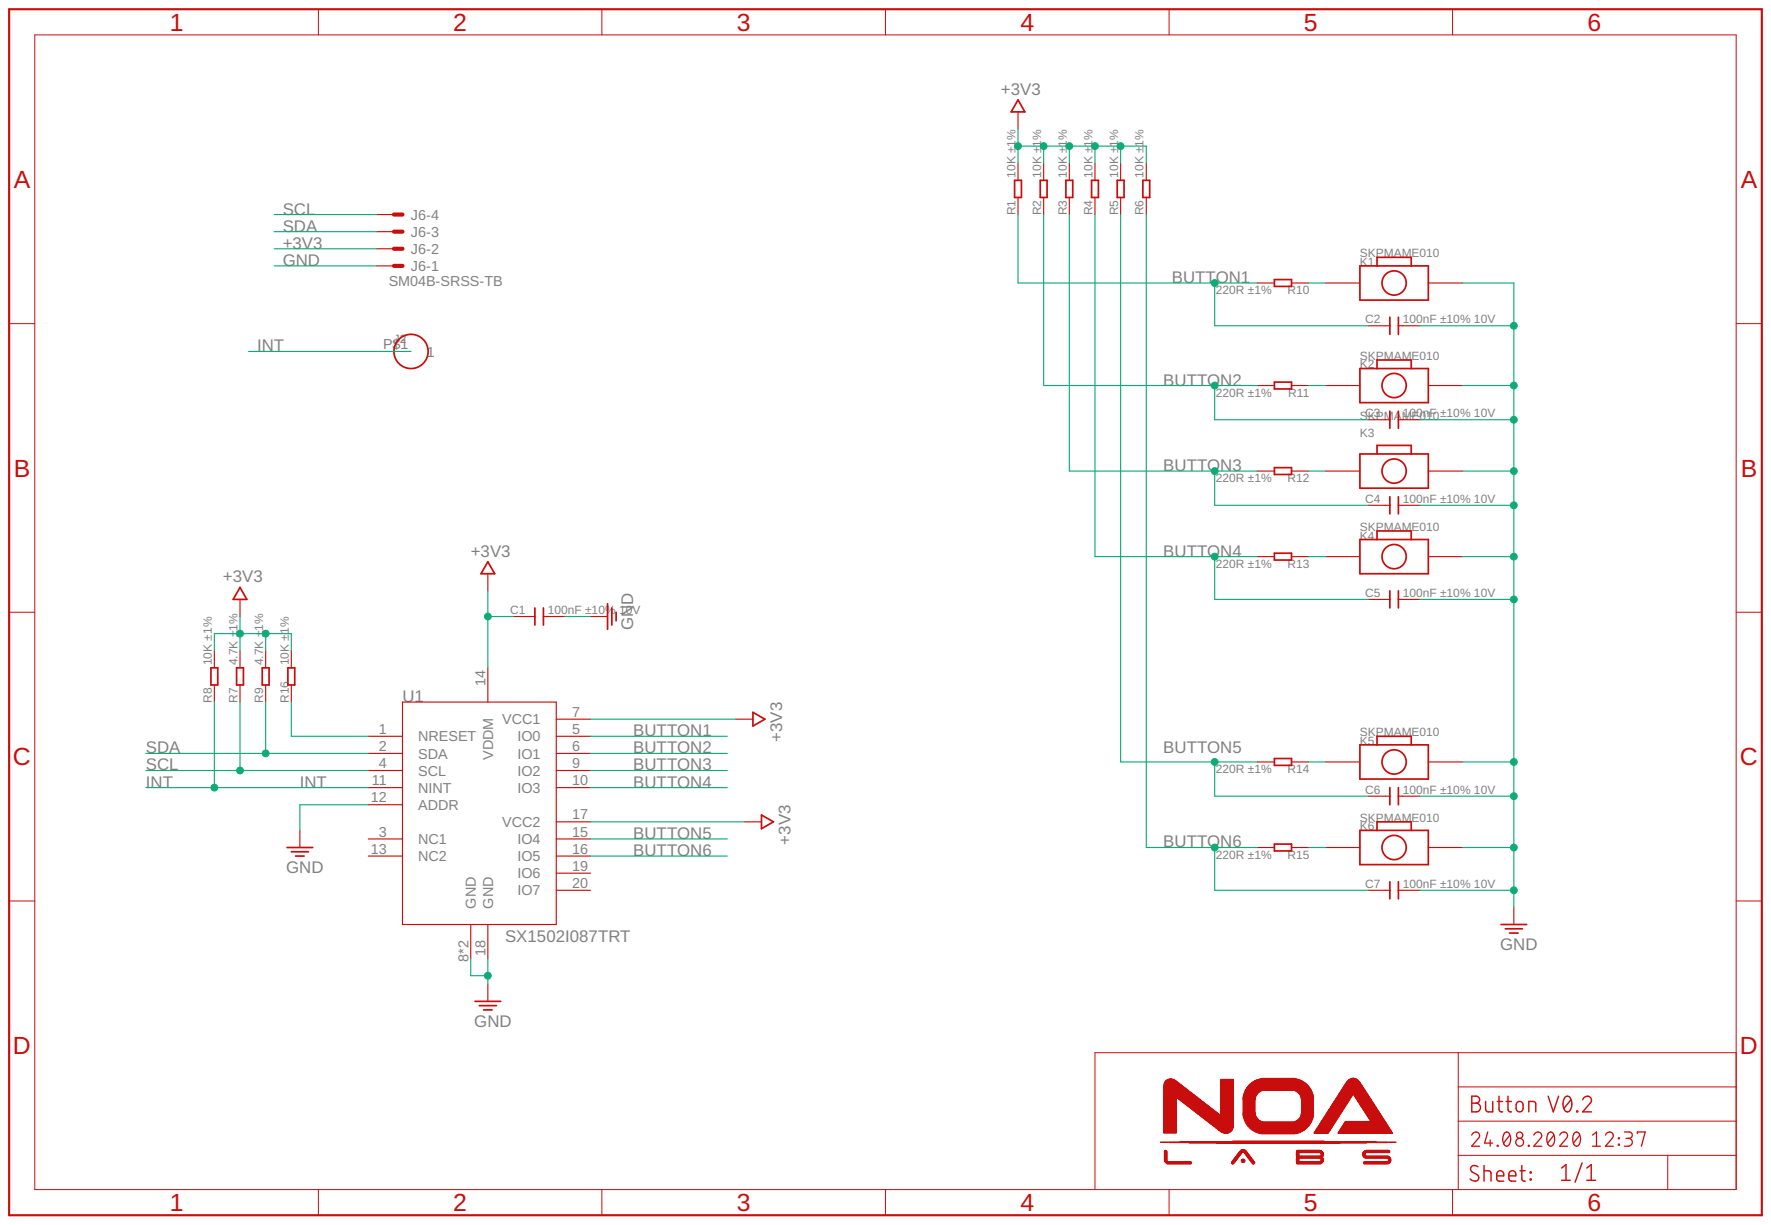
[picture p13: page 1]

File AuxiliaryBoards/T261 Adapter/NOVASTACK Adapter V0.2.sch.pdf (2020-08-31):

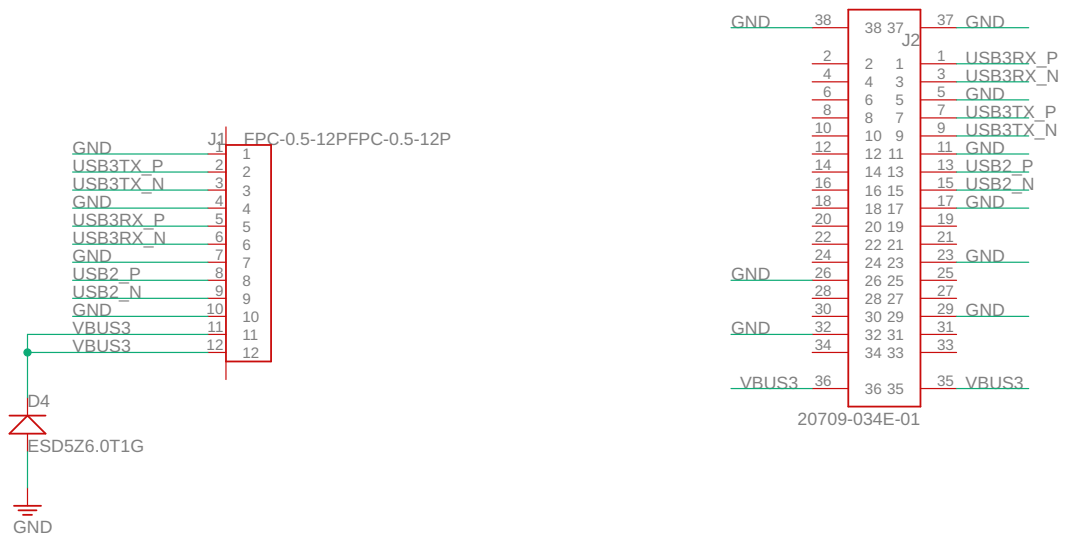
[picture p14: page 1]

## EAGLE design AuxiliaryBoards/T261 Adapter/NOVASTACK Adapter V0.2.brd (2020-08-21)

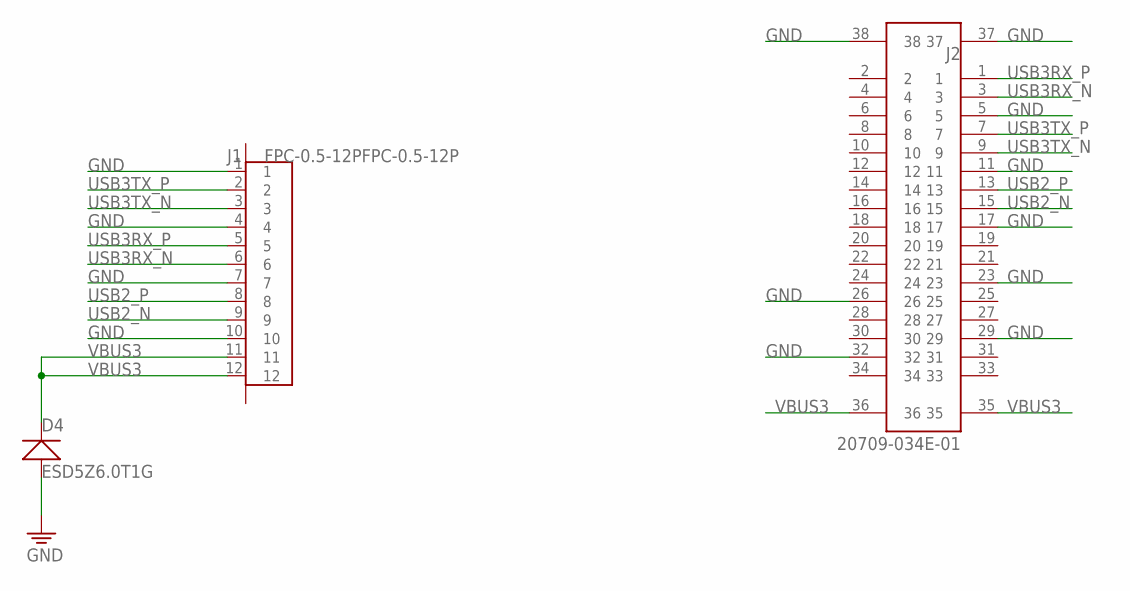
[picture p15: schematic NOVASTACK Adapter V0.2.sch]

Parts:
D4: ESD5Z6.0T1G; SOD523
J1: FPC-0.5-12PFPC-0.5-12P; FPC-0.5-12P
J2: 20709-034E-01; IPEX_20709-034E-01

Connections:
GND: D4.+, J1.1, J1.4, J1.7, J1.10, J2.5, J2.11, J2.17, J2.23, J2.26, J2.29, J2.32, J2.37, J2.38
USB2_N: J1.9, J2.15
USB2_P: J1.8, J2.13
USB3RX_N: J1.6, J2.3
USB3RX_P: J1.5, J2.1
USB3TX_N: J1.3, J2.9
USB3TX_P: J1.2, J2.7
VBUS3: D4.-, J1.11, J1.12, J2.35, J2.36

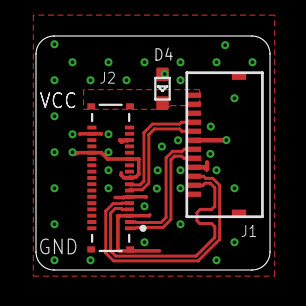
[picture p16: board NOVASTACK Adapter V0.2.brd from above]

Board: 2 copper layers, 13.0 x 13.0 mm, 3 parts (0 on the bottom side), 8 nets.

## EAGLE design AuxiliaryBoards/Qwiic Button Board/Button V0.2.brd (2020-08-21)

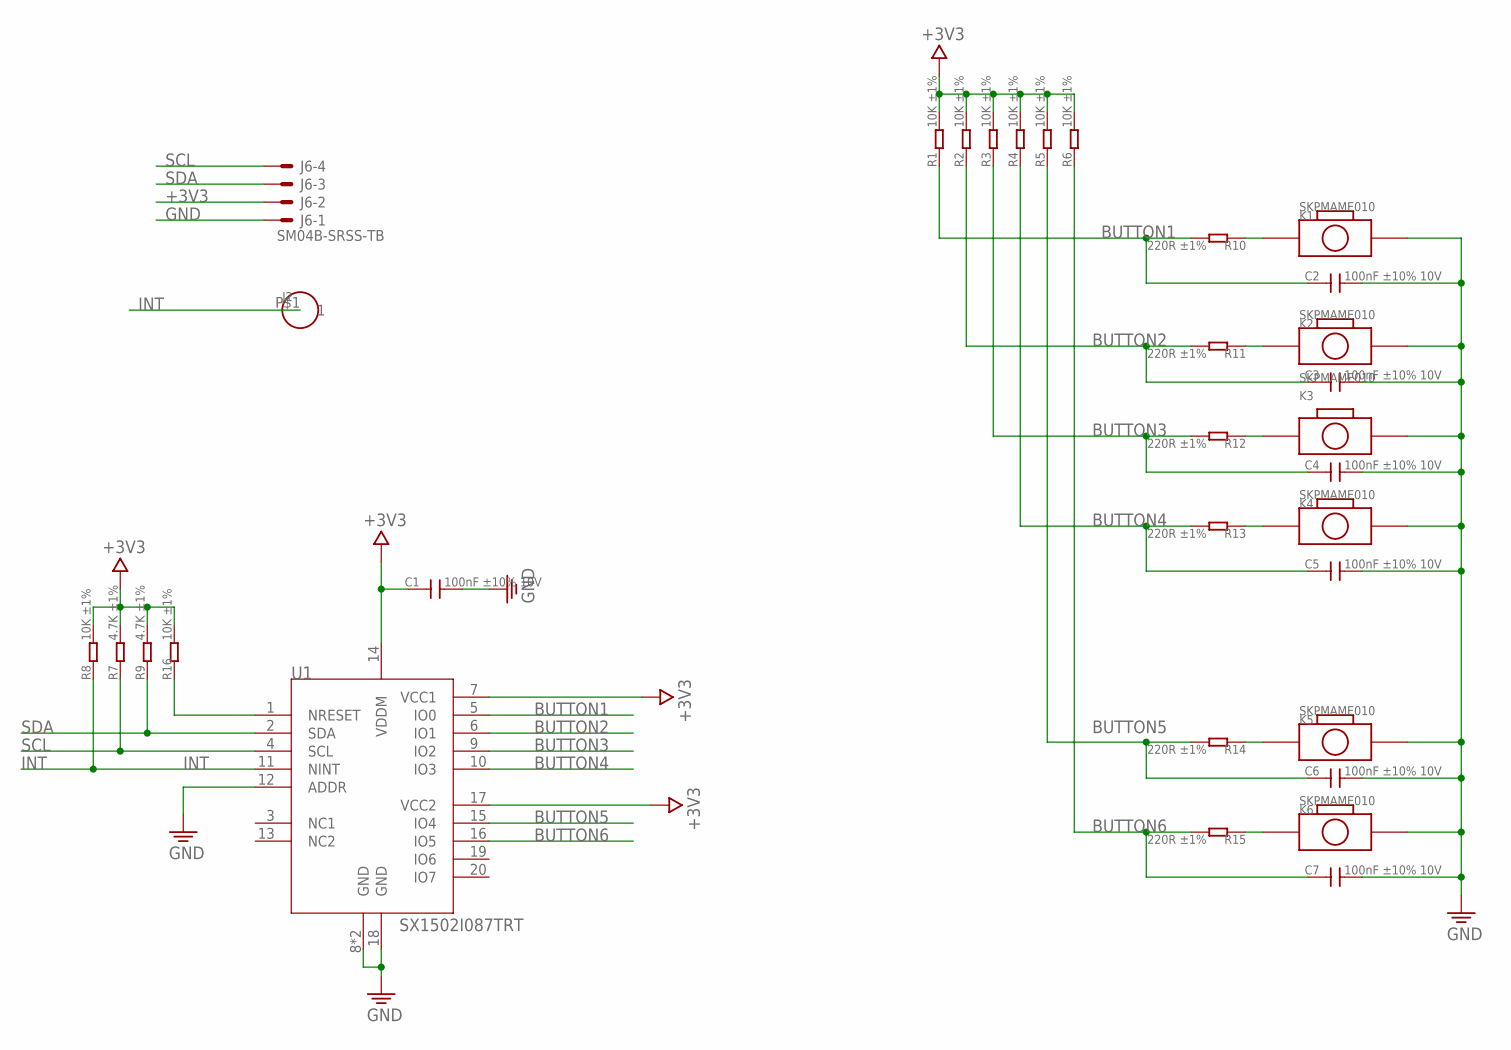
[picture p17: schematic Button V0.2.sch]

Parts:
C1, C2, C3, C4, C5, C6, C7: 100nF ±10% 10V; C0402
J2: HEADER-1P-32; 1P-60/32MIL
J6: SM04B-SRSS-TB
K1, K2, K3, K4, K5, K6: SKPMAME010
R1, R2, R3, R4, R5, R6, R8, R16: 10K ±1%; R0402
R7, R9: 4.7K ±1%; R0402
R10, R11, R12, R13, R14, R15: 220R ±1%; R0402
U1: SX1502I087TRT; QFN-20-3X3MM

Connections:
+3V3: C1.1, J6.2, R1.2, R2.2, R3.2, R4.2, R5.2, R6.2, R7.2, R8.2, R9.2, R16.2, U1.7 (VCC1), U1.14 (VDDM), U1.17 (VCC2)
BUTTON1: C2.1, R1.1, R10.2, U1.5 (IO0)
BUTTON2: C3.1, R2.1, R11.2, U1.6 (IO1)
BUTTON3: C4.1, R3.1, R12.2, U1.9 (IO2)
BUTTON4: C5.1, R4.1, R13.2, U1.10 (IO3)
BUTTON5: C6.1, R5.1, R14.2, U1.15 (IO4)
BUTTON6: C7.1, R6.1, R15.2, U1.16 (IO5)
GND: C1.2, C2.2, C3.2, C4.2, C5.2, C6.2, C7.2, J6.1, K1.2, K2.2, K3.2, K4.2, K5.2, K6.2, U1.8 (GND), U1.12 (ADDR), U1.18 (GND), U1.21 (GND)
INT: J2.P$1, R8.1, U1.11 (NINT)
unnamed: K1.1, R10.1
unnamed: K2.1, R11.1
unnamed: K3.1, R12.1
unnamed: K4.1, R13.1
unnamed: K5.1, R14.1
unnamed: K6.1, R15.1
unnamed: R16.1, U1.1 (NRESET)
SCL: J6.4, R7.1, U1.4 (SCL)
SDA: J6.3, R9.1, U1.2 (SDA)

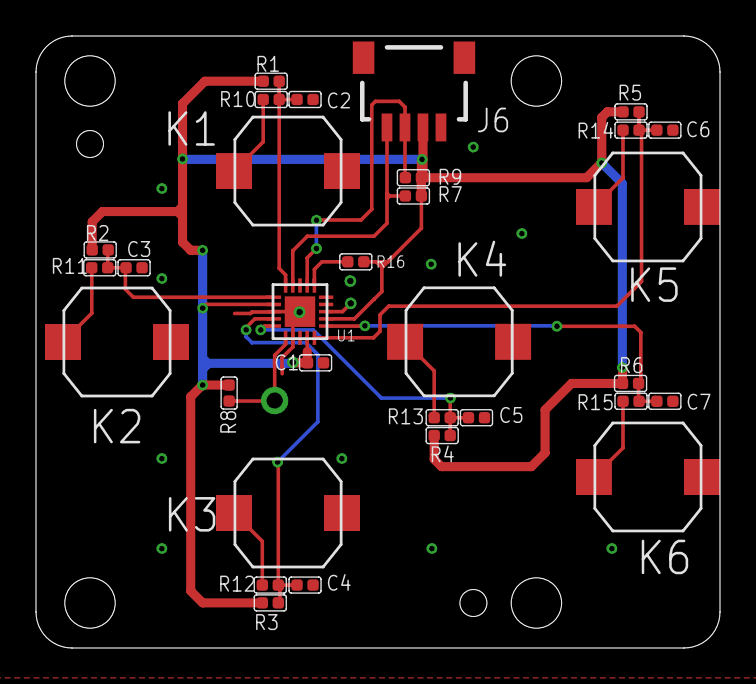
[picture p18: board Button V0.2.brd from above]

Board: 2 copper layers, 38.0 x 34.0 mm, 32 parts (1 on the bottom side), 18 nets.

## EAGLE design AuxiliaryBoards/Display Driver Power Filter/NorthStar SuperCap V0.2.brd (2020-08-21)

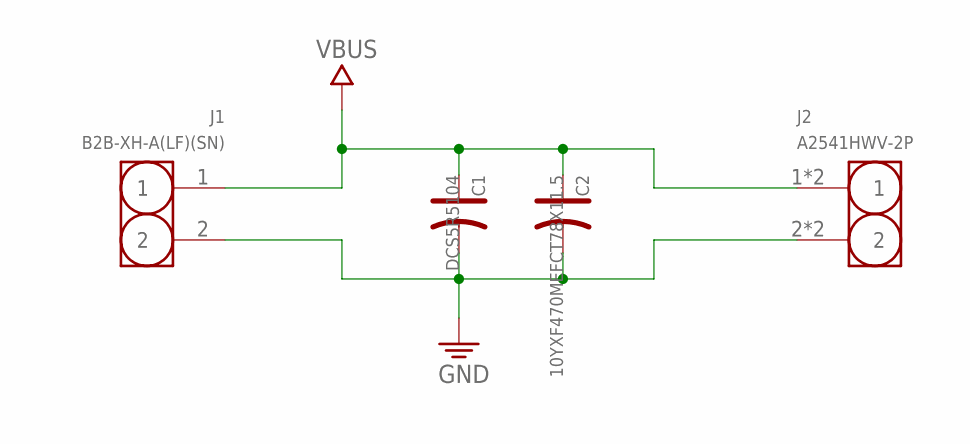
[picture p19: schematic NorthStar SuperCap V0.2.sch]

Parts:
C1: DCS5R5104; 11.5X5.5MM-P10
C2: 10YXF470MEFCT78X11.5; ELECTRO-8.0MM
J1: B2B-XH-A(LF)(SN); XH-02-90
J2: A2541HWV-2P; 2P-2.54-BOTTOM-ENTRY

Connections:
GND: C1.2 (-), C2.-, J1.2, J2.2, J2.2-2 (2)
VBUS: C1.1 (+), C2.+, J1.1, J2.1, J2.1-1 (1)

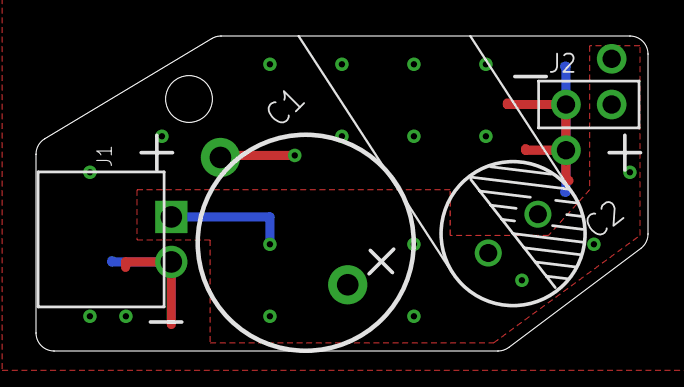
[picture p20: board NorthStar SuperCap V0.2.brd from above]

Board: 2 copper layers, 34.0 x 17.5 mm, 4 parts (0 on the bottom side), 2 nets.

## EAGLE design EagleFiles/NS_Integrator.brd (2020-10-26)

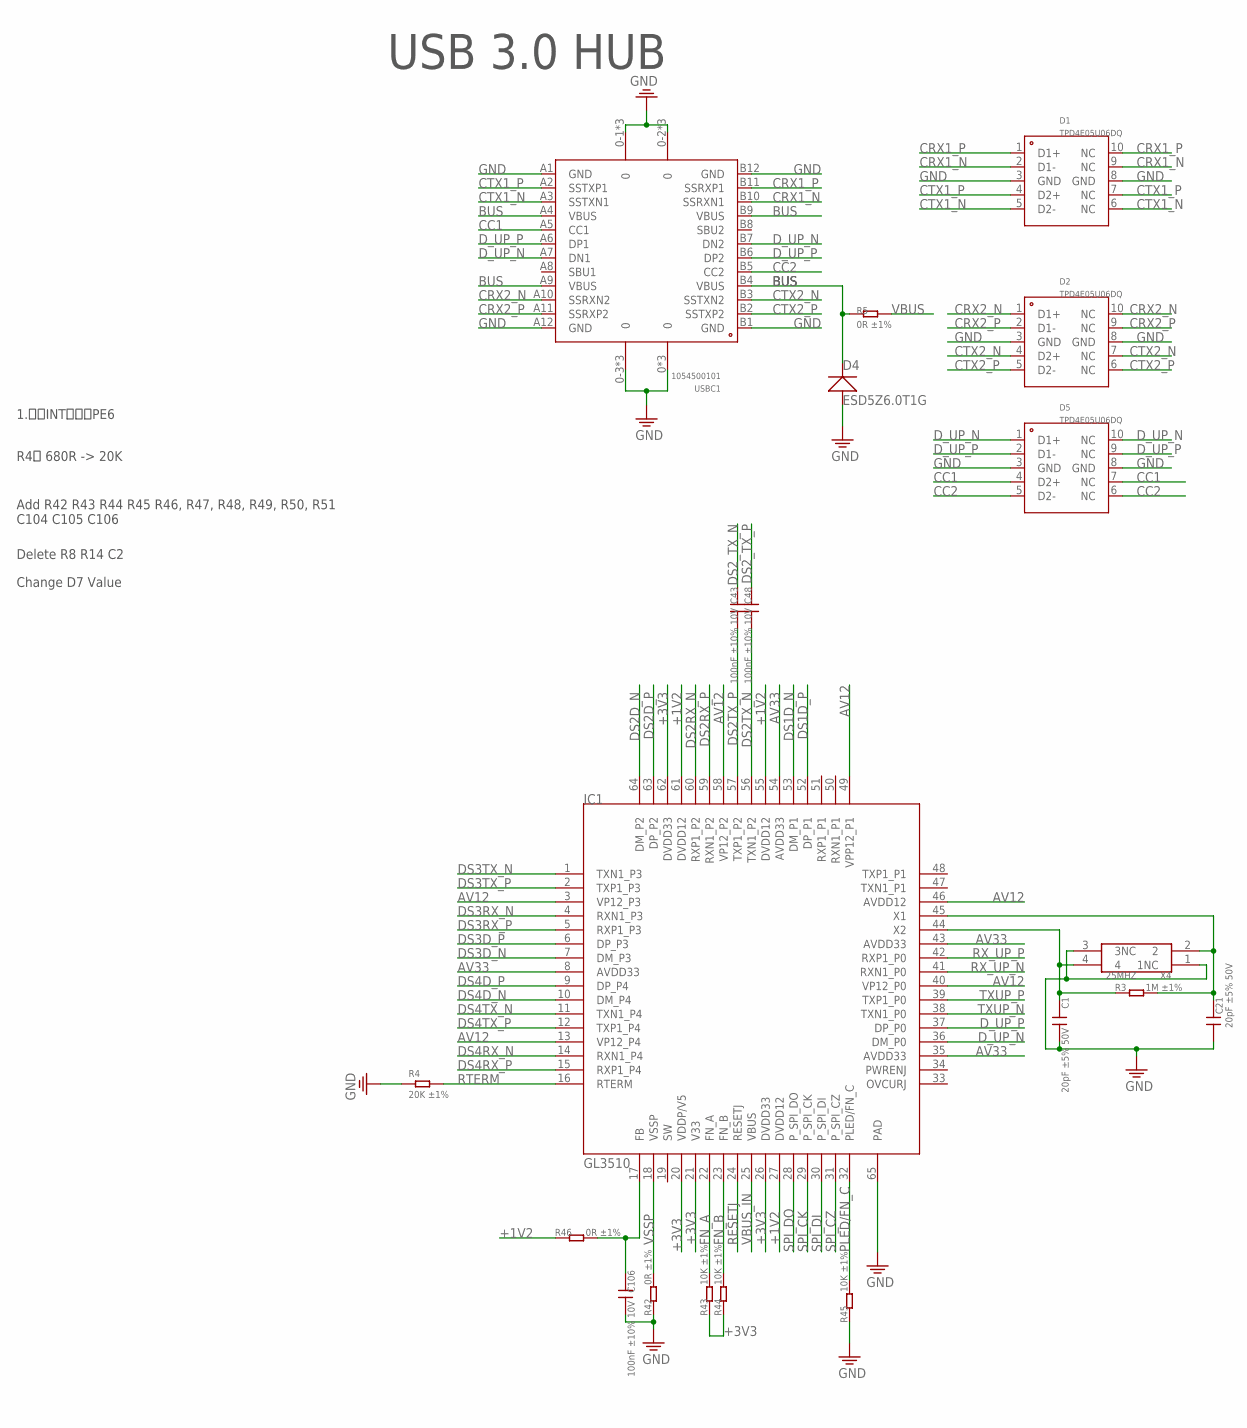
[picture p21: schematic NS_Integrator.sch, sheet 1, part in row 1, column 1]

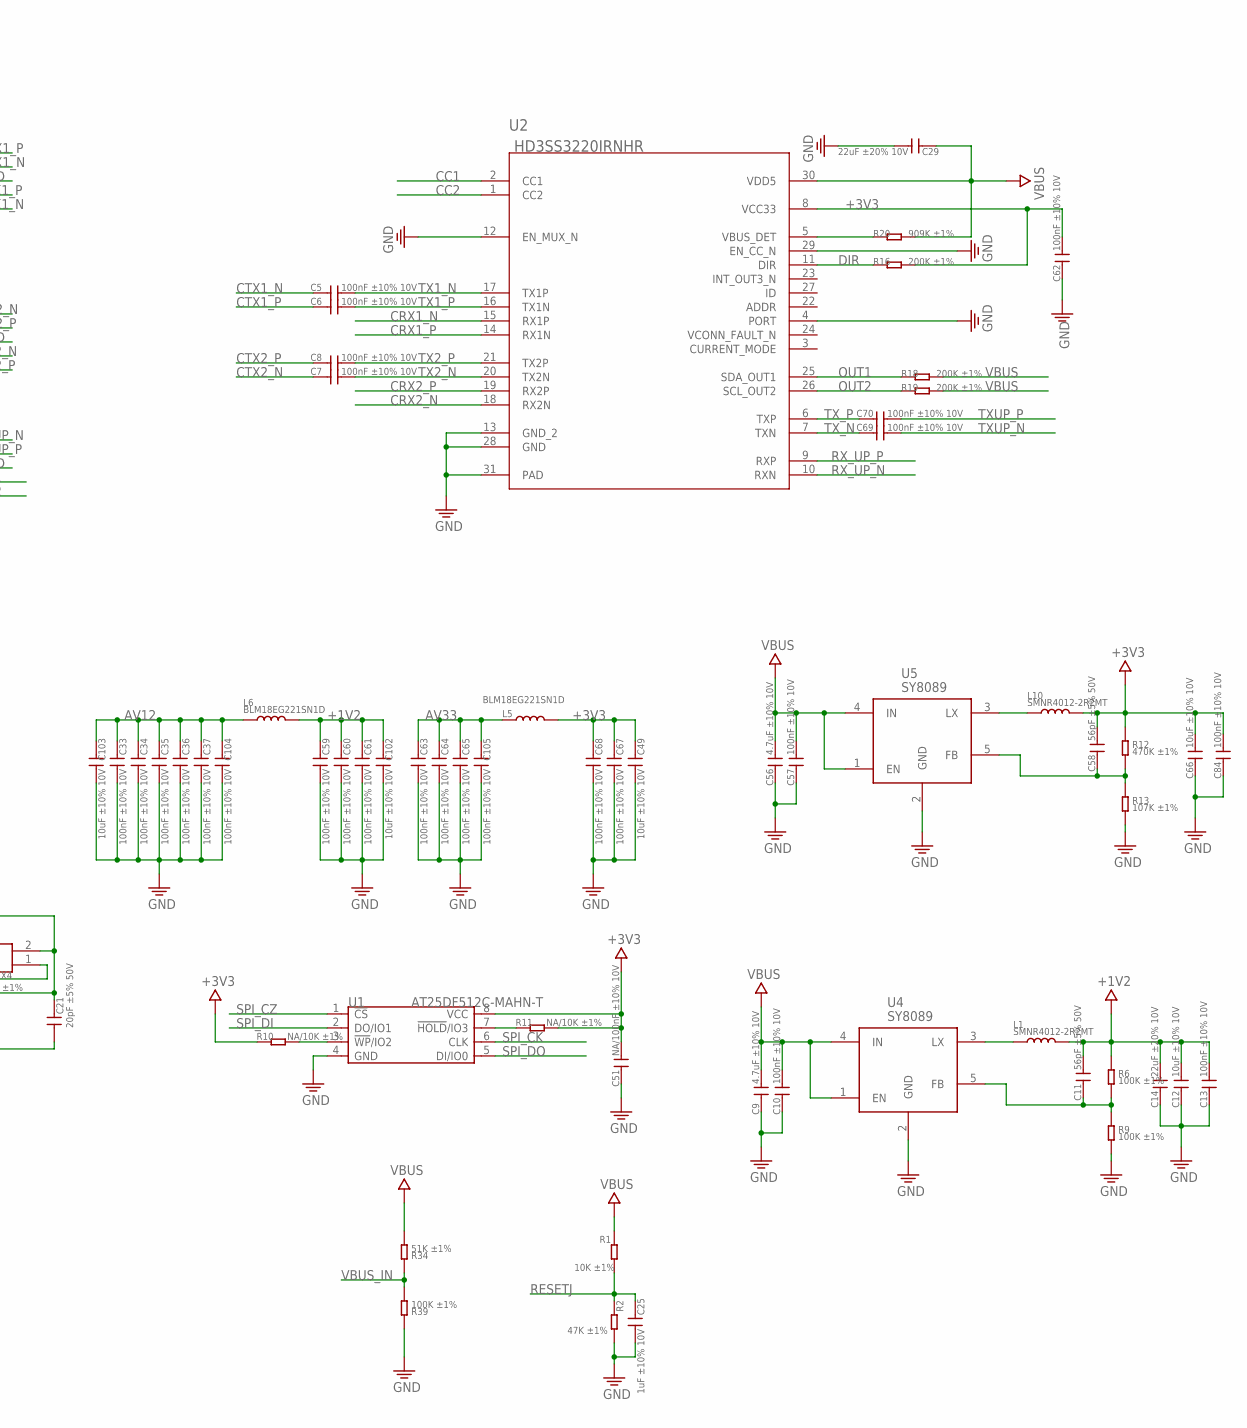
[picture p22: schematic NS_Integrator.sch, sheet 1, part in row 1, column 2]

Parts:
C1, C21: 20pF ±5% 50V; C0402
C5, C6, C7, C8, C43, C48, C69, C70: 100nF ±10% 10V; C0201
C9, C56: 4.7uF ±10% 10V; C0603
C10, C13, C33, C34, C35, C36, C37, C57, C59, C60, C61, C62, C63, C64, C65, C67, C68, C84, C104, C105, C106: 100nF ±10% 10V; C0402
C11, C58: 56pF ±5% 50V; C0402
C12, C49, C66, C102, C103: 10uF ±10% 10V; C0603
C14, C29: 22uF ±20% 10V; C0805
C25: 1uF ±10% 10V; C0402
C51: NA/100nF ±10% 10V; C0402
D1, D2, D5: TPD4E05U06DQ; USON-10_L2.5-W1.0-P0.50-BL
D4: ESD5Z6.0T1G; SOD523
IC1: GL3510; QFN40P800X800X80-65N
L1, L10: SMNR4012-2R2MT; L4012
L5, L6: BLM18EG221SN1D; L0603
R1, R43, R44, R45: 10K ±1%; R0402
R2: 47K ±1%; R0402
R3: 1M ±1%; R0402
R4: 20K ±1%; R0402
R5: 0R ±1%; R0805
R6, R9, R39: 100K ±1%; R0402
R10, R11: NA/10K ±1%; R0402
R12: 470K ±1%; R0402
R13: 107K ±1%; R0402
R16, R18, R19: 200K ±1%; R0402
R20: 909K ±1%; R0402
R34: 51K ±1%; R0402
R42, R46: 0R ±1%; R0402
U1: AT25DF512C-MAHN-T; SOIC8-6.0
U2: HD3SS3220IRNHR; RNH0030A
U4, U5: SY8089; SOT23-5
USBC1: 1054500101; USB-C-SMD_TYPE-C-USB-18
X4: 25MHZ; 4P-SMD-2X1.6MM

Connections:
+1V2: C11.2, C12.2, C13.2, C14.2, C59.1, C60.1, C61.1, C102.1, IC1.27 (DVDD12), IC1.55 (DVDD12), IC1.61 (DVDD12), L1.2, L6.2, R6.1, R46.1
+3V3: C49.1, C51.2, C58.2, C62.2, C66.2, C67.1, C68.1, C84.2, IC1.20 (VDDP/V5), IC1.21 (V33), IC1.26 (DVDD33), IC1.62 (DVDD33), L5.2, L10.2, R10.1, R11.2, R12.1, R16.2, R43.1, R44.1, U1.8 (VCC), U2.8 (VCC33); also elsewhere on the board
AV12: C33.1, C34.1, C35.1, C36.1, C37.1, C103.1, C104.1, IC1.3 (VP12_P3), IC1.13 (VP12_P4), IC1.40 (VP12_P0), IC1.46 (AVDD12), IC1.49 (VPP12_P1), IC1.58 (VP12_P2), L6.1
AV33: C63.1, C64.1, C65.1, C105.1, IC1.8 (AVDD33), IC1.35 (AVDD33), IC1.43 (AVDD33), IC1.54 (AVDD33), L5.1
BUS: D4.-, R5.1, USBC1.A4 (VBUS), USBC1.A9 (VBUS), USBC1.B4 (VBUS), USBC1.B9 (VBUS)
CC1: D5.4 (D2+), D5.7 (NC), U2.2 (CC1), USBC1.A5 (CC1)
CC2: D5.5 (D2-), D5.6 (NC), U2.1 (CC2), USBC1.B5 (CC2)
CRX1_N: D1.2 (D1-), D1.9 (NC), U2.15 (RX1P), USBC1.B10 (SSRXN1)
CRX1_P: D1.1 (D1+), D1.10 (NC), U2.14 (RX1N), USBC1.B11 (SSRXP1)
CRX2_N: D2.1 (D1+), D2.10 (NC), U2.18 (RX2N), USBC1.A10 (SSRXN2)
CRX2_P: D2.2 (D1-), D2.9 (NC), U2.19 (RX2P), USBC1.A11 (SSRXP2)
CTX1_N: C5.1, D1.5 (D2-), D1.6 (NC), USBC1.A3 (SSTXN1)
CTX1_P: C6.1, D1.4 (D2+), D1.7 (NC), USBC1.A2 (SSTXP1)
CTX2_N: C7.1, D2.4 (D2+), D2.7 (NC), USBC1.B3 (SSTXN2)
CTX2_P: C8.1, D2.5 (D2-), D2.6 (NC), USBC1.B2 (SSTXP2)
DIR: R16.1, U2.11 (DIR)
DS1D_N: IC1.53 (DM_P1); also elsewhere on the board
DS1D_P: IC1.52 (DP_P1); also elsewhere on the board
DS2D_N: IC1.64 (DM_P2); also elsewhere on the board
DS2D_P: IC1.63 (DP_P2); also elsewhere on the board
DS2RX_N: IC1.60 (RXP1_P2); also elsewhere on the board
DS2RX_P: IC1.59 (RXN1_P2); also elsewhere on the board
DS2TX_N: C48.2, IC1.56 (TXN1_P2)
DS2TX_P: C43.2, IC1.57 (TXP1_P2)
DS2_TX_N: C43.1; also elsewhere on the board
DS2_TX_P: C48.1; also elsewhere on the board
DS3D_N: IC1.7 (DM_P3); also elsewhere on the board
DS3D_P: IC1.6 (DP_P3); also elsewhere on the board
DS3RX_N: IC1.4 (RXN1_P3); also elsewhere on the board
DS3RX_P: IC1.5 (RXP1_P3); also elsewhere on the board
DS3TX_N: IC1.1 (TXN1_P3); also elsewhere on the board
DS3TX_P: IC1.2 (TXP1_P3); also elsewhere on the board
DS4D_N: IC1.10 (DM_P4); also elsewhere on the board
DS4D_P: IC1.9 (DP_P4); also elsewhere on the board
DS4RX_N: IC1.14 (RXN1_P4); also elsewhere on the board
DS4RX_P: IC1.15 (RXP1_P4); also elsewhere on the board
DS4TX_N: IC1.11 (TXN1_P4); also elsewhere on the board
DS4TX_P: IC1.12 (TXP1_P4); also elsewhere on the board
D_UP_N: D5.1 (D1+), D5.10 (NC), IC1.36 (DM_P0), USBC1.A7 (DN1), USBC1.B7 (DN2)
D_UP_P: D5.2 (D1-), D5.9 (NC), IC1.37 (DP_P0), USBC1.A6 (DP1), USBC1.B6 (DP2)
FN_A: IC1.22 (FN_A), R43.2
FN_B: IC1.23 (FN_B), R44.2
GND: C1.2, C9.1, C10.1, C12.1, C13.1, C14.1, C21.2, C25.2, C29.2, C33.2, C34.2, C35.2, C36.2, C37.2, C49.2, C51.1, C56.1, C57.1, C59.2, C60.2, C61.2, C62.1, C63.2, C64.2, C65.2, C66.1, C67.2, C68.2, C84.1, C102.2, C103.2, C104.2, C105.2, C106.2, D1.3 (GND), D1.8 (GND), D2.3 (GND), D2.8 (GND), D4.+, D5.3 (GND), D5.8 (GND), IC1.65 (PAD), R2.2, R4.1, R9.2, R13.2, R39.1, R42.1, R45.1, U1.4 (GND), U2.4 (PORT), U2.12 (EN_MUX_N), U2.13 (GND_2), U2.28 (GND), U2.29 (EN_CC_N), U2.31 (PAD), U4.2 (GND), U5.2 (GND), USBC1.0, USBC1.0-1 (0), USBC1.0-2 (0), USBC1.0-3 (0), USBC1.0-4 (0), USBC1.0-5 (0), USBC1.0-6 (0), USBC1.0-7 (0), USBC1.0-8 (0), USBC1.0-9 (0), USBC1.1 (0), USBC1.2 (0), USBC1.A1 (GND), USBC1.A12 (GND), USBC1.B1 (GND), USBC1.B12 (GND), X4.1 (1NC), X4.3 (3NC); also elsewhere on the board
unnamed: C1.1, IC1.44 (X2), R3.1, X4.4
unnamed: C106.1, IC1.17 (FB), R46.2
unnamed: C21.1, IC1.45 (X1), R3.2, X4.2
unnamed: C58.1, R12.2, R13.1, U5.5 (FB)
unnamed: L10.1, U5.3 (LX)
unnamed: C11.1, R6.2, R9.1, U4.5 (FB)
unnamed: L1.1, U4.3 (LX)
unnamed: R20.1, U2.5 (VBUS_DET)
unnamed: R10.2, U1.3 (!WP!/IO2)
unnamed: R11.1, U1.7 (!HOLD!/IO3)
OUT1: R18.1, U2.25 (SDA_OUT1)
OUT2: R19.1, U2.26 (SCL_OUT2)
PLED/FN_C: IC1.32 (PLED/FN_C), R45.2
RESETJ: C25.1, IC1.24 (RESETJ), R1.2, R2.1
RTERM: IC1.16 (RTERM), R4.2
RX_UP_N: IC1.41 (RXN1_P0), U2.10 (RXN)
RX_UP_P: IC1.42 (RXP1_P0), U2.9 (RXP)
SPI_CK: IC1.29 (P_SPI_CK), U1.6 (CLK)
SPI_CZ: IC1.31 (P_SPI_CZ), U1.1 (!CS)
SPI_DI: IC1.30 (P_SPI_DI), U1.2 (DO/IO1)
SPI_DO: IC1.28 (P_SPI_DO), U1.5 (DI/IO0)
TX1_N: C5.2, U2.17 (TX1P)
TX1_P: C6.2, U2.16 (TX1N)
TX2_N: C7.2, U2.20 (TX2N)
TX2_P: C8.2, U2.21 (TX2P)
TXUP_N: C69.2, IC1.38 (TXN1_P0)
TXUP_P: C70.2, IC1.39 (TXP1_P0)
TX_N: C69.1, U2.7 (TXN)
TX_P: C70.1, U2.6 (TXP)
VBUS: C9.2, C10.2, C29.1, C56.2, C57.2, R1.1, R5.2, R18.2, R19.2, R20.2, R34.2, U2.30 (VDD5), U4.1 (EN), U4.4 (IN), U5.1 (EN), U5.4 (IN); also elsewhere on the board
VBUS_IN: IC1.25 (VBUS), R34.1, R39.2
VSSP: IC1.18 (VSSP), R42.2

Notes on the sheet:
USB 3.0 HUB
1.修改INT中断为PE6
R4： 680R -> 20K
Add R42 R43 R44 R45 R46, R47, R48, R49, R50, R51 C104 C105 C106
Delete R8 R14 C2
Change D7 Value

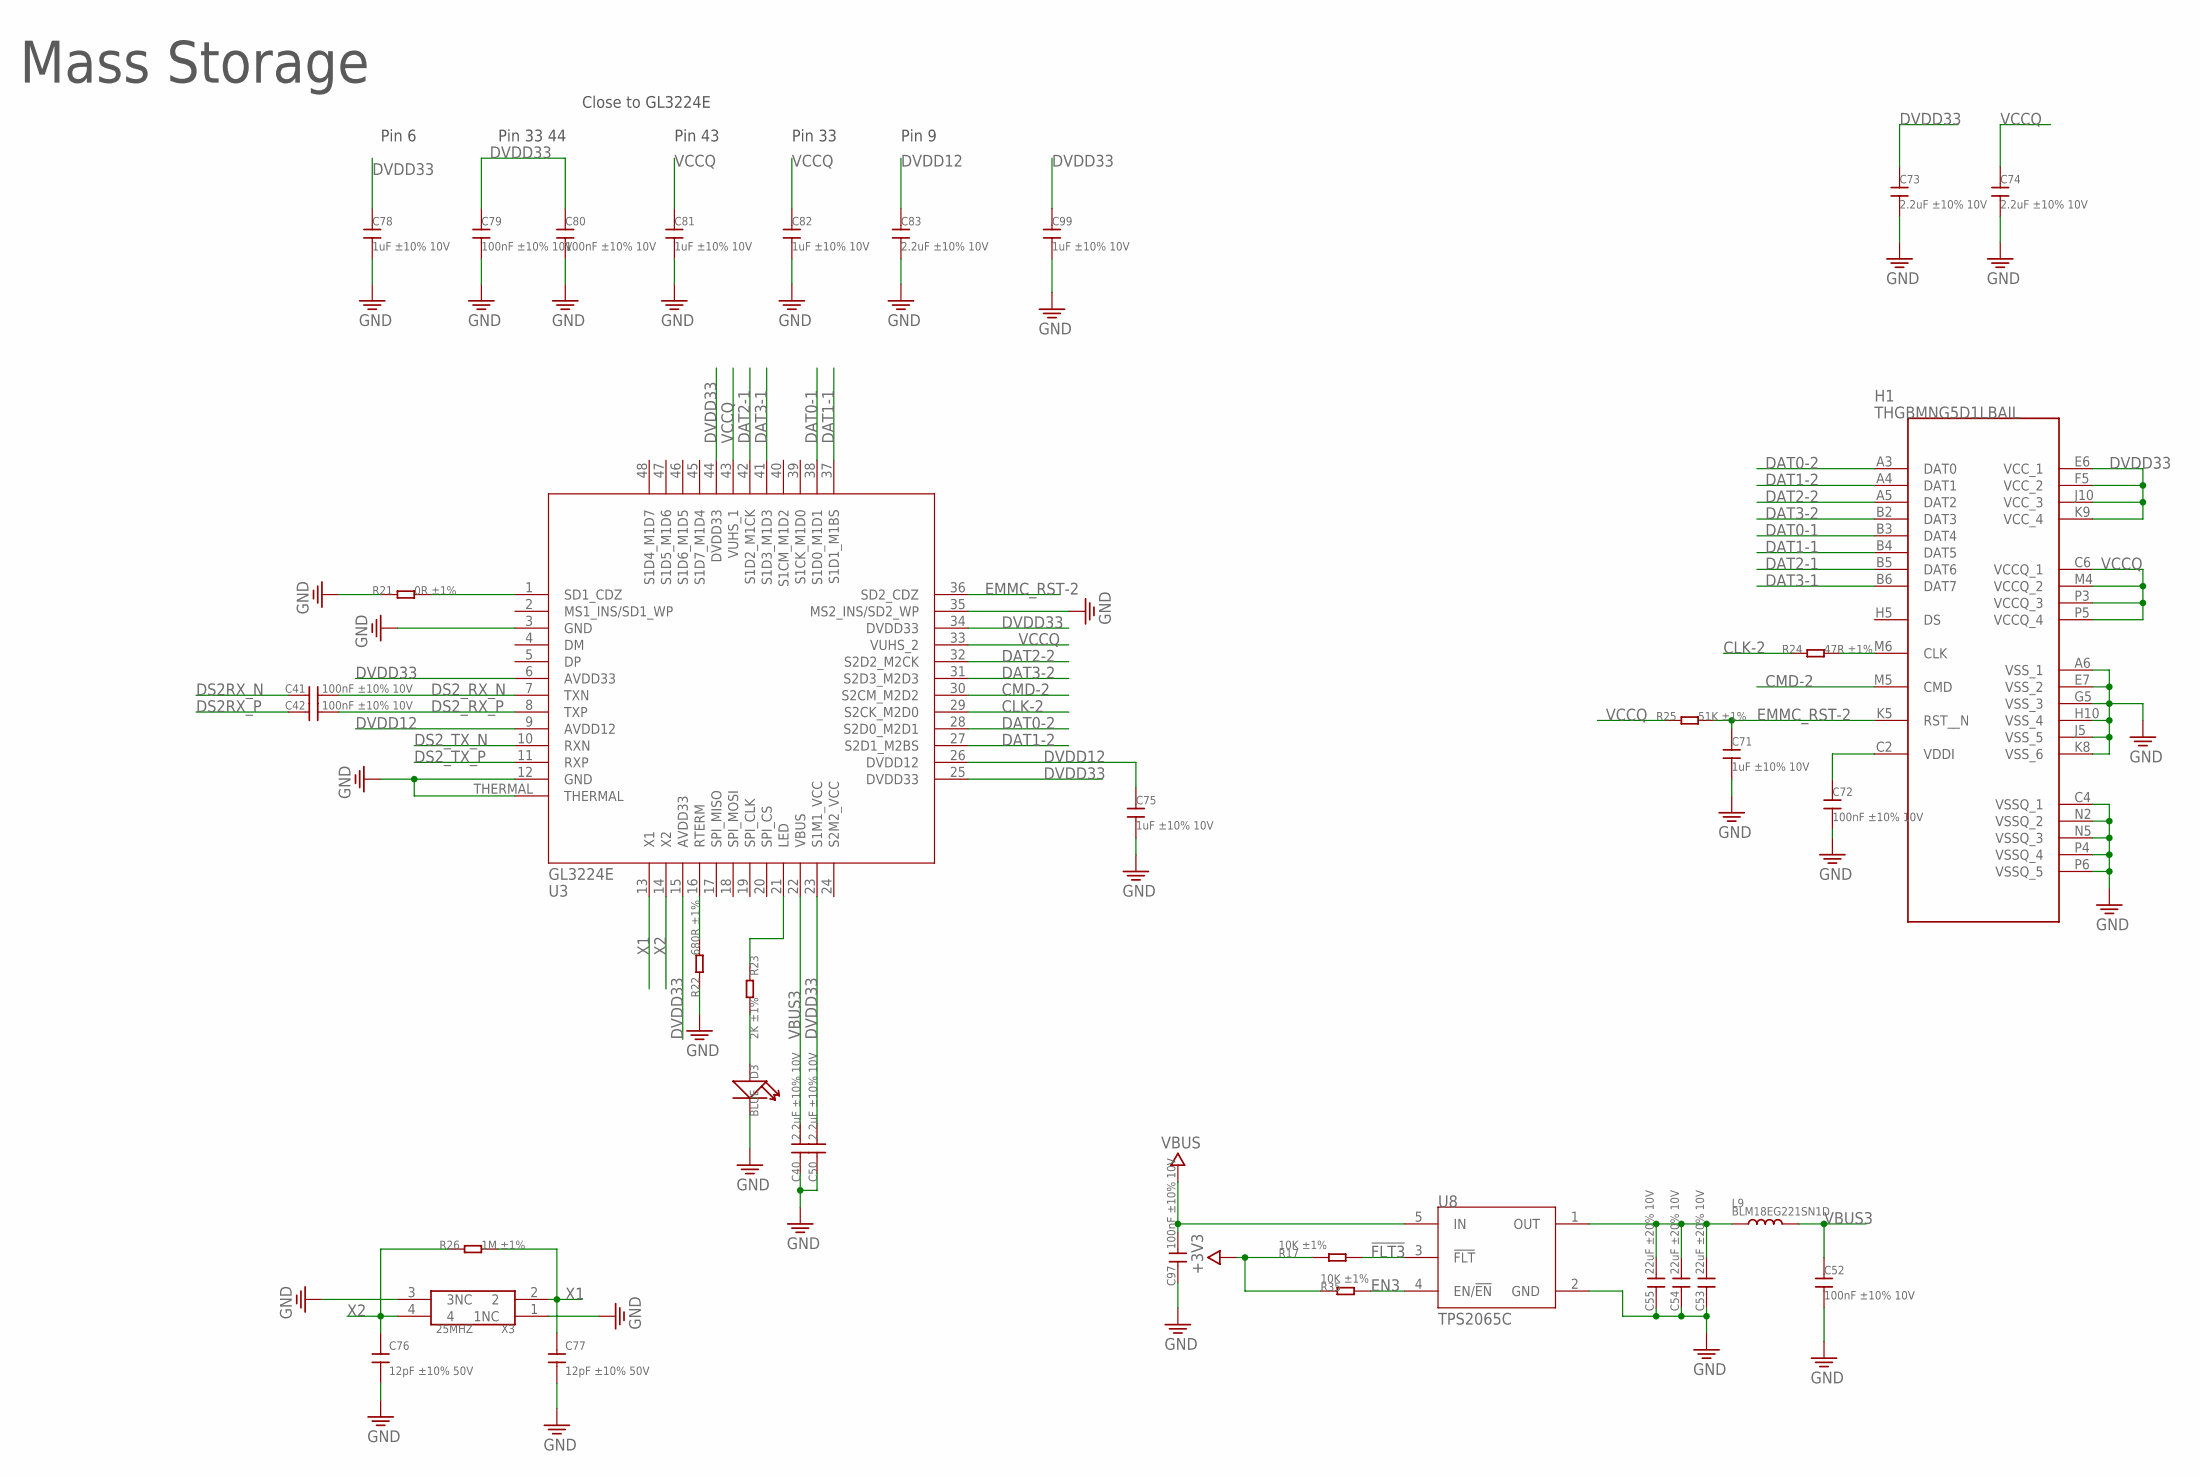
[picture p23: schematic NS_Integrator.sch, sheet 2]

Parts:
C40, C50, C73, C74, C83: 2.2uF ±10% 10V; C0402
C41, C42: 100nF ±10% 10V; C0201
C52, C72, C79, C80, C97: 100nF ±10% 10V; C0402
C53, C54, C55: 22uF ±20% 10V; C0603
C71, C75, C78, C81, C82, C99: 1uF ±10% 10V; C0402
C76, C77: 12pF ±10% 50V; C0402
D3: BLUE; 0402_LED
H1: THGBMNG5D1LBAIL; BGA153C50P14X14_11.5X13
L9: BLM18EG221SN1D; L0603
R17, R35: 10K ±1%; R0402
R21: 0R ±1%; R0402
R22: 680R ±1%; R0402
R23: 2K ±1%; R0402
R24: 47R ±1%; R0402
R25: 51K ±1%; R0402
R26: 1M ±1%; R0402
U3: GL3224E; TQFN48_7MM
U8: TPS2065C; SOT23-5
X3: 25MHZ; 4P-SMD-2X1.6MM

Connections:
!FLT3: R17.2, U8.3 (!FLT); also elsewhere on the board
+3V3: R17.1, R35.1; also elsewhere on the board
CLK-2: R24.1, U3.29 (S2CK_M2D0)
CMD-2: H1.M5 (CMD), U3.30 (S2CM_M2D2)
DAT0-1: H1.B3 (DAT4), U3.38 (S1D0_M1D1)
DAT0-2: H1.A3 (DAT0), U3.28 (S2D0_M2D1)
DAT1-1: H1.B4 (DAT5), U3.37 (S1D1_M1BS)
DAT1-2: H1.A4 (DAT1), U3.27 (S2D1_M2BS)
DAT2-1: H1.B5 (DAT6), U3.42 (S1D2_M1CK)
DAT2-2: H1.A5 (DAT2), U3.32 (S2D2_M2CK)
DAT3-1: H1.B6 (DAT7), U3.41 (S1D3_M1D3)
DAT3-2: H1.B2 (DAT3), U3.31 (S2D3_M2D3)
DS2RX_N: C41.1; also elsewhere on the board
DS2RX_P: C42.1; also elsewhere on the board
DS2_RX_N: C41.2, U3.7 (TXN)
DS2_RX_P: C42.2, U3.8 (TXP)
DS2_TX_N: U3.10 (RXN); also elsewhere on the board
DS2_TX_P: U3.11 (RXP); also elsewhere on the board
DVDD12: C75.2, C83.2, U3.9 (AVDD12), U3.26 (DVDD12)
DVDD33: C50.2, C73.2, C78.2, C79.2, C80.2, C99.2, H1.E6 (VCC_1), H1.F5 (VCC_2), H1.J10 (VCC_3), H1.K9 (VCC_4), U3.6 (AVDD33), U3.15 (AVDD33), U3.23 (S1M1_VCC), U3.25 (DVDD33), U3.34 (DVDD33), U3.44 (DVDD33)
EMMC_RST-2: C71.2, H1.K5 (RST__N), R25.2, U3.36 (SD2_CDZ)
EN3: R35.2, U8.4 (EN/!EN); also elsewhere on the board
GND: C40.1, C50.1, C52.2, C53.1, C54.1, C55.1, C71.1, C72.1, C73.1, C74.1, C75.1, C76.2, C77.2, C78.1, C79.1, C80.1, C81.1, C82.1, C83.1, C97.1, C99.1, D3.2 (-), H1.A6 (VSS_1), H1.C4 (VSSQ_1), H1.E7 (VSS_2), H1.G5 (VSS_3), H1.H10 (VSS_4), H1.J5 (VSS_5), H1.K8 (VSS_6), H1.N2 (VSSQ_2), H1.N5 (VSSQ_3), H1.P4 (VSSQ_4), H1.P6 (VSSQ_5), R21.1, R22.1, U3.3 (GND), U3.12 (GND), U3.35 (MS2_INS/SD2_WP), U3.THERMAL, U8.2 (GND), X3.1 (1NC), X3.3 (3NC); also elsewhere on the board
unnamed: H1.M6 (CLK), R24.2
unnamed: C72.2, H1.C2 (VDDI)
unnamed: C53.2, C54.2, C55.2, L9.1, U8.1 (OUT)
unnamed: R23.1, U3.21 (LED)
unnamed: D3.1 (+), R23.2
unnamed: R21.2, U3.1 (SD1_CDZ)
unnamed: R22.2, U3.16 (RTERM)
VBUS: C97.2, U8.5 (IN); also elsewhere on the board
VBUS3: C40.2, C52.1, L9.2, U3.22 (VBUS)
VCCQ: C74.2, C81.2, C82.2, H1.C6 (VCCQ_1), H1.M4 (VCCQ_2), H1.P3 (VCCQ_3), H1.P5 (VCCQ_4), R25.1, U3.33 (VUHS_2), U3.43 (VUHS_1)
X1: C77.1, R26.2, U3.13 (X1), X3.2
X2: C76.1, R26.1, U3.14 (X2), X3.4

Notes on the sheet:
Pin 6
Pin 33 44
Pin 43
Pin 33
Pin 9
Close to GL3224E
Mass Storage

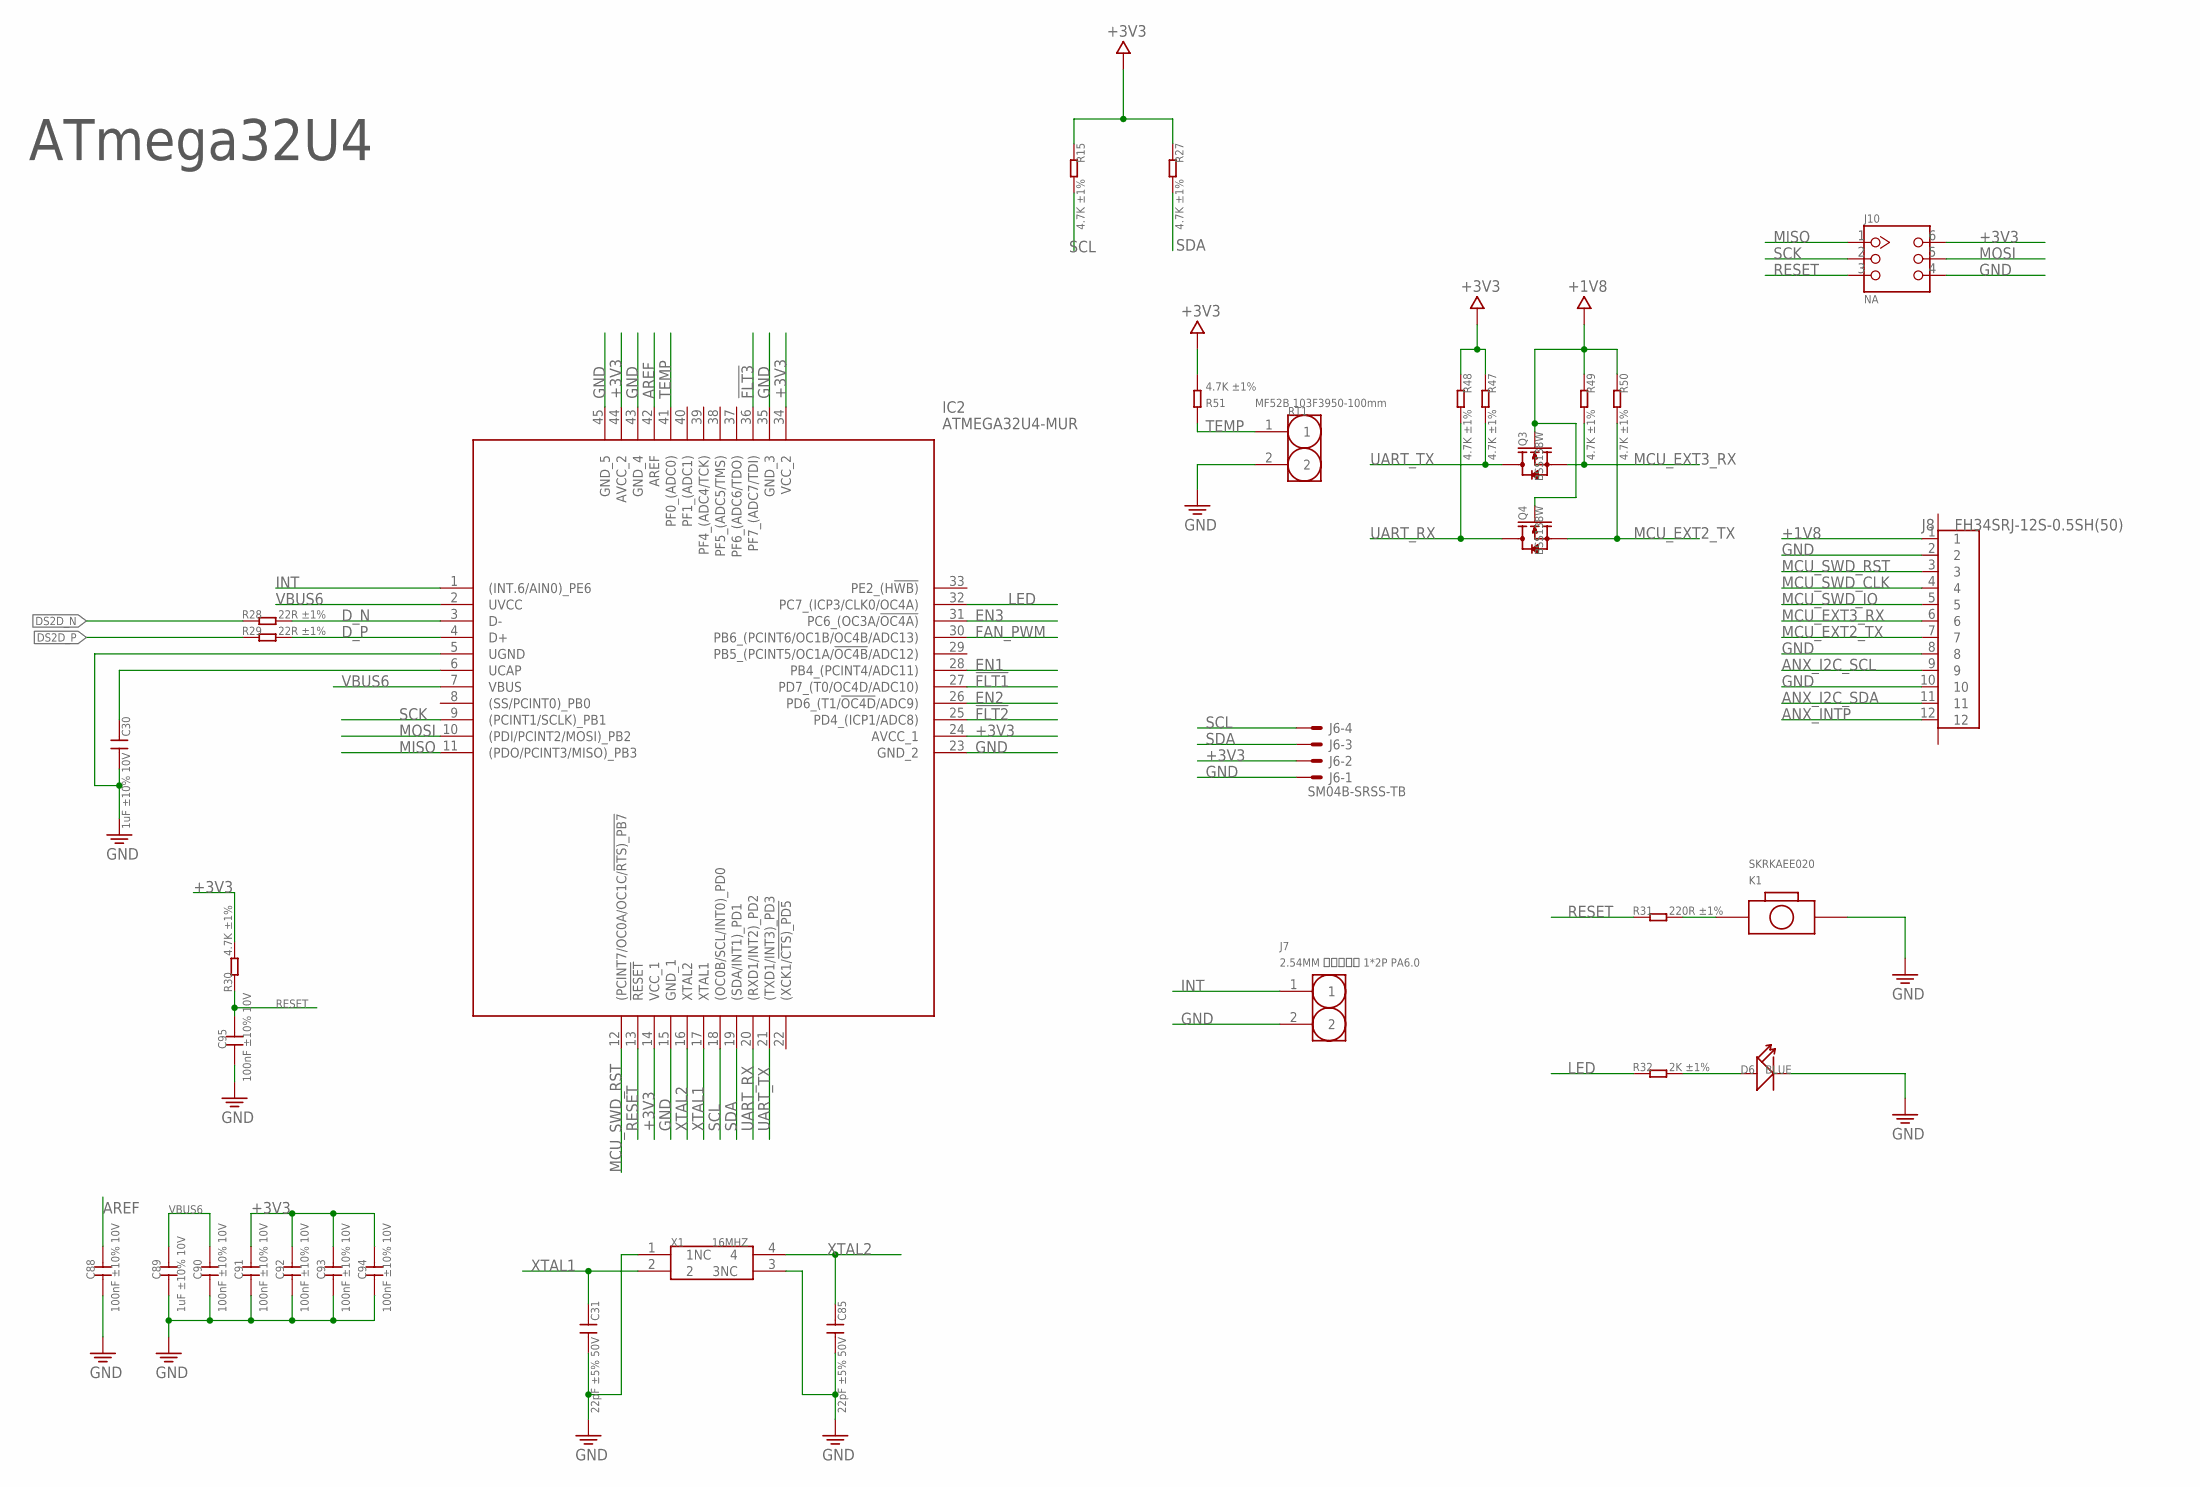
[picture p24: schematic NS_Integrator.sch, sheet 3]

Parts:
C30, C89: 1uF ±10% 10V; C0402
C31, C85: 22pF ±5% 50V; C0402
C88, C90, C91, C92, C93, C94, C95: 100nF ±10% 10V; C0402
D6: BLUE; 0402_LED
IC2: ATMEGA32U4-MUR; QFN50P700X700X100-45N
J6: SM04B-SRSS-TB
J7: 2.54MM 单排正弯针 1*2P PA6.0; 2P-2.54-65/35MIL
J8: FH34SRJ-12S-0.5SH(50); FPC-0.5-12P
J10: NA; 2X3P-2.54-65/35MIL
K1: SKRKAEE020
Q3, Q4: BSS138W; SOT-323
R15, R27, R30, R47, R48, R49, R50, R51: 4.7K ±1%; R0402
R28, R29: 22R ±1%; R0402
R31: 220R ±1%; R0402
R32: 2K ±1%; R0402
RT1: MF52B 103F3950-100mm; 2P-1.27
X1: 16MHZ; 4P-SMD-3.2X2.5

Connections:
!FLT1: IC2.27 (PD7_(T0/OC4D/ADC10)); also elsewhere on the board
!FLT2: IC2.25 (PD4_(ICP1/ADC8)); also elsewhere on the board
!FLT3: IC2.36 (PF7_(ADC7/TDI)); also elsewhere on the board
+1V8: J8.1, Q3.1 (G), Q4.1 (G), R49.1, R50.1
+3V3: C91.1, C92.1, C93.1, C94.1, IC2.14 (VCC_1), IC2.24 (AVCC_1), IC2.34 (VCC_2), IC2.44 (AVCC_2), J6.2, J10.6, R15.1, R27.1, R30.2, R47.1, R48.1, R51.1; also elsewhere on the board
ANX_I2C_SCL: J8.9
ANX_I2C_SDA: J8.11
ANX_INTP: J8.12
AREF: C88.1, IC2.42 (AREF)
DS2D_N: R28.1; also elsewhere on the board
DS2D_P: R29.1; also elsewhere on the board
D_N: IC2.3 (D-), R28.2
D_P: IC2.4 (D+), R29.2
EN1: IC2.28 (PB4_(PCINT4/ADC11)); also elsewhere on the board
EN2: IC2.26 (PD6_(T1/!OC4D!/ADC9)); also elsewhere on the board
EN3: IC2.31 (PC6_(OC3A/!OC4A)); also elsewhere on the board
FAN_PWM: IC2.30 (PB6_(PCINT6/OC1B/OC4B/ADC13)); also elsewhere on the board
GND: C30.2, C31.2, C85.2, C88.2, C89.2, C90.2, C91.2, C92.2, C93.2, C94.2, C95.2, D6.2 (-), IC2.5 (UGND), IC2.15 (GND_1), IC2.23 (GND_2), IC2.35 (GND_3), IC2.43 (GND_4), IC2.45 (GND_5), J6.1, J7.2, J8.2, J8.8, J8.10, J10.4, K1.2, RT1.2, X1.1 (1NC), X1.3 (3NC); also elsewhere on the board
INT: IC2.1 ((INT.6/AIN0)_PE6), J7.1
LED: IC2.32 (PC7_(ICP3/CLK0/OC4A)), R32.1
MCU_EXT2_TX: J8.7, Q4.2 (S), R50.2
MCU_EXT3_RX: J8.6, Q3.2 (S), R49.2
MCU_SWD_CLK: J8.4
MCU_SWD_IO: J8.5
MCU_SWD_RST: IC2.12 ((PCINT7/OC0A/OC1C/!RTS)_PB7), J8.3
MISO: IC2.11 ((PDO/PCINT3/MISO)_PB3), J10.1
MOSI: IC2.10 ((PDI/PCINT2/MOSI)_PB2), J10.5
unnamed: C30.1, IC2.6 (UCAP)
unnamed: K1.1, R31.2
unnamed: D6.1 (+), R32.2
RESET: C95.1, IC2.13 (!RESET), J10.3, R30.1, R31.1
SCK: IC2.9 ((PCINT1/SCLK)_PB1), J10.2
SCL: IC2.18 ((OC0B/SCL/INT0)_PD0), J6.4, R15.2
SDA: IC2.19 ((SDA/INT1)_PD1), J6.3, R27.2
TEMP: IC2.41 (PF0_(ADC0)), R51.2, RT1.1
UART_RX: IC2.20 ((RXD1/INT2)_PD2), Q4.3 (D), R48.2
UART_TX: IC2.21 ((TXD1/INT3)_PD3), Q3.3 (D), R47.2
VBUS6: C89.1, C90.1, IC2.2 (UVCC), IC2.7 (VBUS); also elsewhere on the board
XTAL1: C31.1, IC2.17 (XTAL1), X1.2
XTAL2: C85.1, IC2.16 (XTAL2), X1.4

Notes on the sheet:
ATmega32U4

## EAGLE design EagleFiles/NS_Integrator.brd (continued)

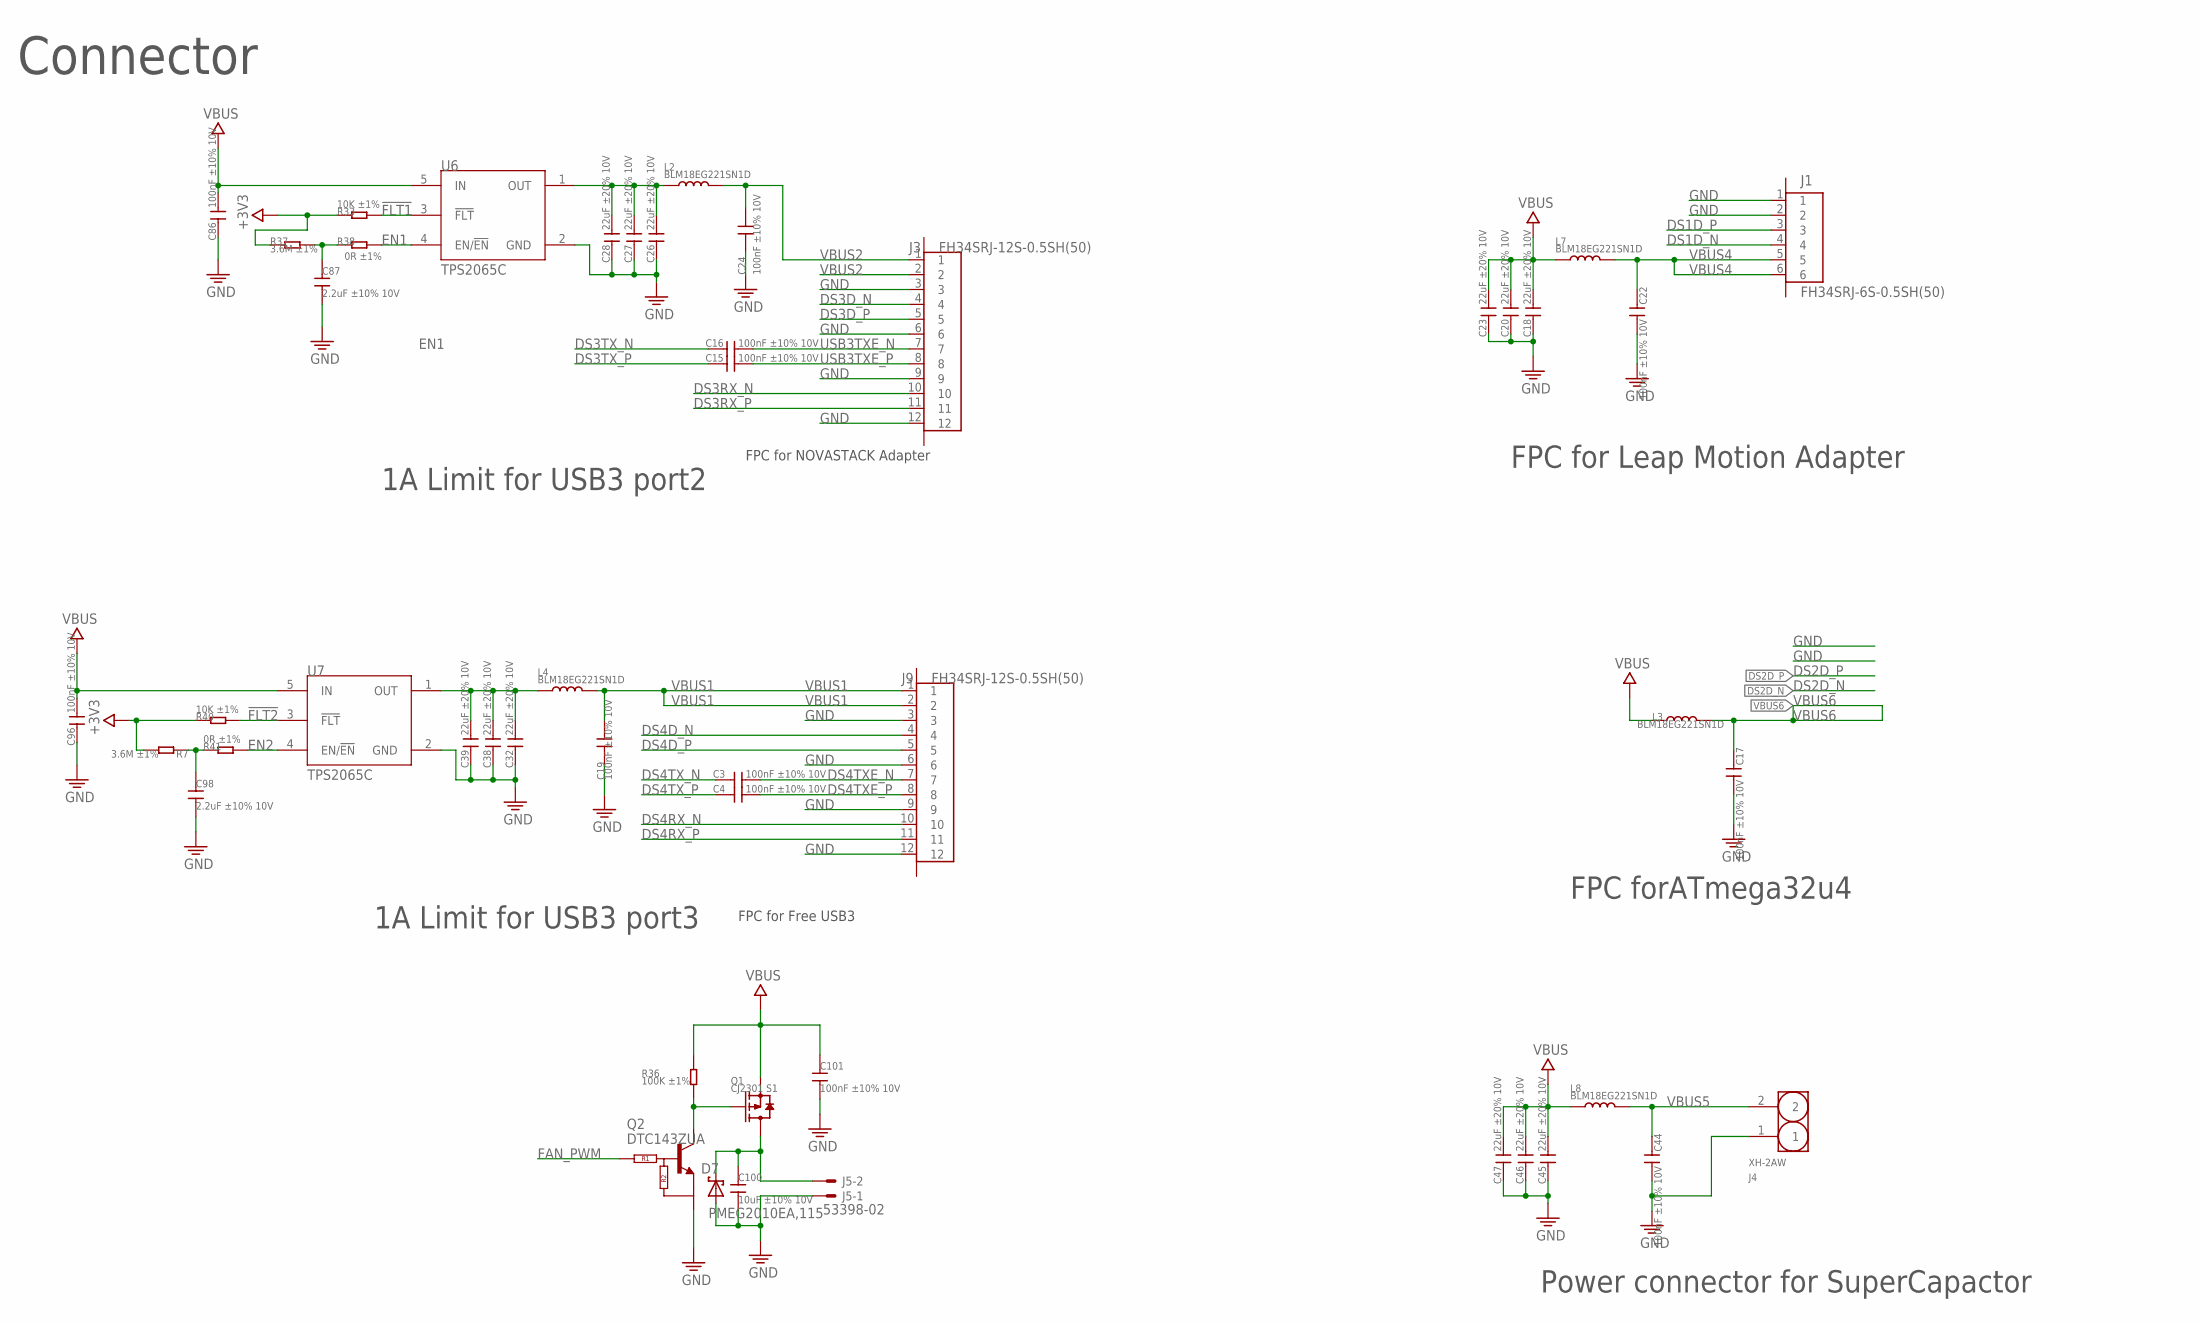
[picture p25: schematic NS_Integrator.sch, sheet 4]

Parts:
C3, C4, C15, C16: 100nF ±10% 10V; C0201
C17, C19, C22, C24, C44, C86, C96, C101: 100nF ±10% 10V; C0402
C18, C20, C23, C26, C27, C28, C32, C38, C39, C45, C46, C47: 22uF ±20% 10V; C0603
C87, C98: 2.2uF ±10% 10V; C0402
C100: 10uF ±10% 10V; C0603
D7: PMEG2010EA,115; SOD323
J1: FH34SRJ-6S-0.5SH(50); FH34RJ-6S
J3, J9: FH34SRJ-12S-0.5SH(50); FPC-0.5-12P
J4: XH-2AW; XH-02-90
J5: 53398-02
L2, L3, L4, L7, L8: BLM18EG221SN1D; L0603
Q1: CJ2301 S1; SOT23
Q2: DTC143ZUA; SOT323
R7, R37: 3.6M ±1%; R0402
R33, R40: 10K ±1%; R0402
R36: 100K ±1%; R0402
R38, R41: 0R ±1%; R0402
U6, U7: TPS2065C; SOT23-5

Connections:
!FLT1: R33.2, U6.3 (!FLT); also elsewhere on the board
!FLT2: R40.2, U7.3 (!FLT); also elsewhere on the board
+3V3: R7.1, R33.1, R37.2, R40.1; also elsewhere on the board
DS1D_N: J1.4; also elsewhere on the board
DS1D_P: J1.3; also elsewhere on the board
DS3D_N: J3.4; also elsewhere on the board
DS3D_P: J3.5; also elsewhere on the board
DS3RX_N: J3.10; also elsewhere on the board
DS3RX_P: J3.11; also elsewhere on the board
DS3TX_N: C16.1; also elsewhere on the board
DS3TX_P: C15.1; also elsewhere on the board
DS4D_N: J9.4; also elsewhere on the board
DS4D_P: J9.5; also elsewhere on the board
DS4RX_N: J9.10; also elsewhere on the board
DS4RX_P: J9.11; also elsewhere on the board
DS4TXE_N: C3.2, J9.7
DS4TXE_P: C4.2, J9.8
DS4TX_N: C3.1; also elsewhere on the board
DS4TX_P: C4.1; also elsewhere on the board
EN1: R38.1, U6.4 (EN/!EN); also elsewhere on the board
EN2: R41.2, U7.4 (EN/!EN); also elsewhere on the board
FAN_PWM: Q2.1 (INPUT); also elsewhere on the board
GND: C17.2, C18.1, C19.2, C20.1, C22.2, C23.1, C24.2, C26.1, C27.1, C28.1, C32.1, C38.1, C39.1, C44.2, C45.1, C46.1, C47.1, C86.1, C87.1, C96.1, C98.1, C100.1, C101.2, D7.+ (A), J1.1, J1.2, J3.3, J3.6, J3.9, J3.12, J4.1, J5.1, J9.3, J9.6, J9.9, J9.12, Q2.2 (E), U6.2 (GND), U7.2 (GND); also elsewhere on the board
unnamed: C98.2, R7.2, R41.1
unnamed: Q1.1 (G), Q2.3 (C), R36.1
unnamed: C26.2, C27.2, C28.2, L2.1, U6.1 (OUT)
unnamed: C87.2, R37.1, R38.2
unnamed: C32.2, C38.2, C39.2, L4.1, U7.1 (OUT)
unnamed: C100.2, D7.- (C), J5.2, Q1.3 (D)
USB3TXE_N: C16.2, J3.7
USB3TXE_P: C15.2, J3.8
VBUS: C18.2, C20.2, C23.2, C45.2, C46.2, C47.2, C86.2, C96.2, C101.1, L3.1, L7.1, L8.1, Q1.2 (S), R36.2, U6.5 (IN), U7.5 (IN); also elsewhere on the board
VBUS1: C19.1, J9.1, J9.2, L4.2
VBUS2: C24.1, J3.1, J3.2, L2.2
VBUS4: C22.1, J1.5, J1.6, L7.2
VBUS5: C44.1, J4.2, L8.2
VBUS6: C17.1, L3.2; also elsewhere on the board

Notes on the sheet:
FPC for Leap Motion Adapter
FPC for NOVASTACK Adapter
FPC forATmega32u4
FPC for Free USB3
1A Limit for USB3 port2
1A Limit for USB3 port3
Power connector for SuperCapactor
Connector

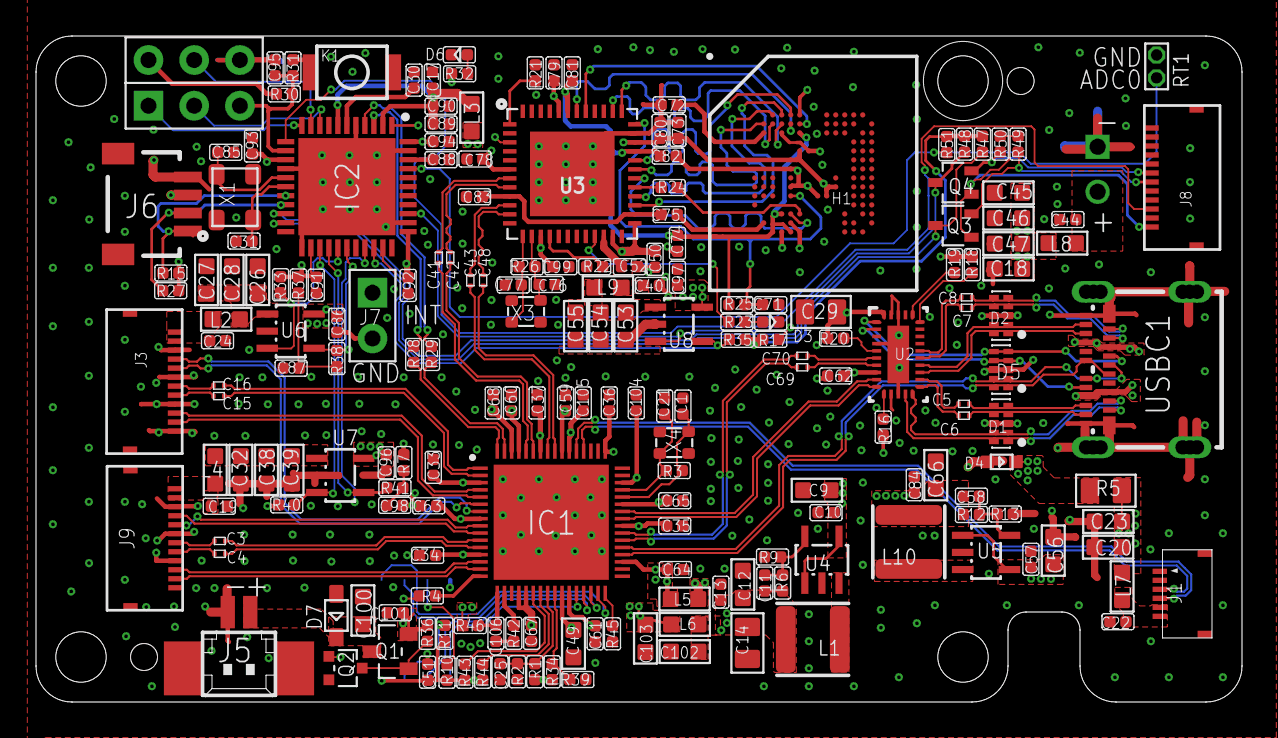
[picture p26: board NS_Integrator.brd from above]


Board: 4 copper layers, 67.0 x 37.0 mm, 201 parts (2 on the bottom side), 146 nets.

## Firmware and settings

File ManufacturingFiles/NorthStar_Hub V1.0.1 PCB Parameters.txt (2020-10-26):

PCB parameters:

PCB Material : FR-4
PCB Layers : 4
Thickness : 1.0mm
Copper Weight : 1 oz
PCB Color : Green
Silkscreen Color : White
Pads Finish : Lead-Free
Via Solder mask : Solder mask cover
Board Size(mm) : 67 x 37mm 
嘉立创 JLC2313层压结构

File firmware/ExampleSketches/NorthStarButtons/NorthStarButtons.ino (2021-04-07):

/*
   Preloaded example sketch for the Combine Reality Deck X Integrator Hub for Project North Star headsets
   Written by Noah Zerkin in 2020
    Do as you will with it, which I guess would make it MIT License? Let's go with that.
   Only stipulation: Don't use it as part of anything that will, by design, hurt anybody.
   I accept no liability for anything. If you live in a jurisdiction where that won't fly, don't run my poorly-written code.
   This sketch started out based on an example from the Sparkfun SX1509 library. Enjoy.
*/

#include <Wire.h> // I2C support library

/*Include SX1508 IO Expander Library. This is a modified version of the Sparkfun SX1509 Library.
   The SX1508 is the 8-pin varient, which has a different register map than the 16-pin SX1509.
*/
#include <SX1508.h>
#include "Keyboard.h"
#include <avr/pgmspace.h>

#define DEBUG 1

// Pin assignments
#define ARDUINO_INT_PIN 7 // SX1508 int output to D7
#define FAN 10          //5v fan circuit control (pwm of a MOSFET)
#define STORAGE 5       //Mass Storage subsystem power control
#define PORT_1 8        //USB 3 Port 1 power control
#define PORT_2 12       //USB 3 Port 2 power control
#define DISP_RST 11     //Display Driver Board reset. Integrator v1.01 and higher

// SX1508 I2C address
const byte SX1508_ADDRESS = 0x20;  // SX1508 I2C address
SX1508 buttonIO; // Create an SX1508 object for the Button Board

// Global variables:
bool buttonPressed = false; // Track button press in ISR
bool buttonsFailed = false; // Let's make sure the button board is actually there
const short BUTTON_DELAY = 200; //ms to wait for a dual press detection
const short RESET_DELAY = 2000; //ms to wait before executing dual press function

long buttonTimer[6] = {0, 0, 0, 0, 0, 0};   //place to store the time of each new button press
short portResetDuration = 500;              //time in ms to hold the reset state of the USB ports
long portResetTimeout = 0;                  //place to the time when the USB port power should be restored during a reset cycle
bool portResetting = false;                 //reset in progress boolean
byte timerMask = 0x00;                      //bits to denote whether a time recorded in the matching slot of buttonTimer is still relevant

bool serialPassthrough = false;

//Boolean to track if a ButtonFP function should be executed
bool buttonAction[6] = {0, 0, 0, 0, 0, 0};

//Array of function pointers for each button on the Integrator Button Board
typedef void (* FP)();
FP ButtonFP[6] = {&down, &right, &up, &left, &circle, &dot};

//Global bool to turn keycode output on or off, in case we want to switch to a different button function set
bool keyboardOutput = true;

//Array of keyboard keycodes to be sent for each of the buttons on the Integrator Button Board
byte keycode[6] = {KEY_DOWN_ARROW, KEY_RIGHT_ARROW, KEY_UP_ARROW, KEY_LEFT_ARROW, 0x5B, 0x5D};
// Keycodes can be ASCII chars or hex, or come from a limited set of preprocessor definitions defined here:
// https://github.com/arduino-libraries/Keyboard/blob/master/src/Keyboard.h
// Assuming that you want the buttons on the Integrator Button Board to send keyboard keys,
// this is someplace where you can keep and easily reassign them.
// By default, they are assigned to the arrow keys and '[' and ']', used to adjust IPD, eye elevation, and eye relief in the original
// Project North Star Unity example scene using v1 calibration.
// The array index for each keycode can coorespond to the the index of the pointer to the function from which you want to send it.
// That way we can easily change the keycodes in one place, or switch to an alternate keycode set.
// This can be expanded upon by using a reassignable pointer to this and other arrays of keycodes.
// Alternatively, we could add an additional dimension to this array.
//
// https://www.arduino.cc/reference/en/language/functions/usb/keyboard/
//

void setup()
{
  pinMode(ARDUINO_INT_PIN, INPUT_PULLUP);
  pinMode(FAN, OUTPUT);
  pinMode(PORT_1, OUTPUT);
  pinMode(PORT_2, OUTPUT);
  pinMode(STORAGE, OUTPUT);
  pinMode(DISP_RST, OUTPUT);

  //Start with USB 3 ports and onboard mass storage subsystems powered up
  digitalWrite(PORT_2, HIGH);
  digitalWrite(PORT_1, HIGH);
  digitalWrite(STORAGE, HIGH);
  digitalWrite(DISP_RST, HIGH);

  // Initialize Serial port for debug output (or to relay serial i/o from display driver board with Integrator v1.01 or greater)
  Serial.begin(9600);
  // Initialize Serial1 port to communicate with display driver board using Integrator v1.01 or greater
  Serial1.begin(500000);

  // Call buttonIO.begin(<address>) to initialize the SX1508. If
  // it successfully communicates, it'll return 1.
  if (!buttonIO.begin(SX1508_ADDRESS))
  {
    Serial.println("Failed to communicate.");
    buttonsFailed = true;
    delay(500);
  }

  // buttonIO.configForNorthStarButtons();


  // Use buttonIO.pinMode(<pin>, <mode>) to set our button to an
  // input with internal pullup resistor activated:
  // buttonIO.writeByte(REG_INPUT_DISABLE, 0b11000000);
  // buttonIO.writeByte(REG_PULL_UP, 0b00111111);
  //  buttonIO.pinMode(SX1508_BUTTON_PIN, INPUT_PULLUP);
  if (!buttonsFailed) {
    for (byte i = 0; i < 6; i++) {
      buttonIO.pinMode(i, INPUT_PULLUP);
      delay(1);
    }

    // Use buttonIO.enableInterrupt(<pin>, <signal>) to enable an
    // interrupt on a pin. The <signal> variable can be either
    // FALLING, RISING, or CHANGE. Set it to falling, which will
    // mean the button was pressed:
    //  for (byte i = 0; i < 5; i++) {
    //    buttonIO.enableInterrupt(i, FALLING);
    //    delay(1);
    //  }

    // Seems I broke the enableInterrupt() function in Sparkfun's SX1509 library when modifying it for SX1508.
    // Writing to the registers inline for now. - Noah
    buttonIO.writeByte(0x09, 0b11000000);
    buttonIO.writeByte(0x0A, 0b00001111);
    buttonIO.writeByte(0x0B, 0b11111111);

    // The SX1508 has built-in debounce features, so a single
    // button-press doesn't accidentally create multiple ints.
    // Use buttonIO.debounceTime(<time_ms>) to set the GLOBAL SX1508
    // debounce time.
    // <time_ms> can be either 0, 1, 2, 4, 8, 16, 32, or 64 ms.
    buttonIO.debounceTime(32); // Set debounce time to 32 ms.

    // After configuring the debounce time, use
    //debouncePin(<pin>) to enable debounce on an input pin.
    for (byte i = 0; i < 6; i++) {
      buttonIO.debouncePin(i);
    }

    // Attach an Arduino interrupt to the interrupt pin (ARDUINO_INT_PIN). Call
    // the button function to set the buttonPressed flag whenever the pin goes from HIGH to
    // LOW.
    attachInterrupt(digitalPinToInterrupt(ARDUINO_INT_PIN),
                    button, FALLING);
  }
  digitalWrite(STORAGE, HIGH);
  analogWrite(FAN, 160);
  digitalWrite(PORT_2, HIGH);
  digitalWrite(PORT_1, HIGH);
  Keyboard.begin();
  Keyboard.releaseAll();
}

void loop()
{
  if (buttonPressed) // If the button() ISR was executed
  {
    buttonPressed = false; // Clear the buttonPressed flag
#if DEBUG
    Serial.println("Int triggered");
#endif
    // read buttonIO.interruptSource() find out which pin generated
    // an interrupt and clear the SX1508's interrupt output.
    byte intStatus = buttonIO.interruptSource(true);
    byte buttonStatus = 0xFF ^ buttonIO.readData(); // Read and invert button data byte, since buttons are active-low
    if (!buttonStatus) {
      Keyboard.releaseAll();
    }
#if DEBUG
    // Each bit in intStatus represents a single SX1508 IO.
    Serial.println("intStatus = " + String(intStatus, BIN) + " buttonStatus = " + String(buttonStatus, BIN));
#endif

    byte pressed = intStatus | buttonStatus;
    byte buttonNum = 0;
    byte numPressed = 0;
    for (byte i = 0; i < 6; i++) {
      if (intStatus & (1 << i)) {
        buttonNum = i;
#if DEBUG
        Serial.print("Button " + String(buttonNum) + " was ");
#endif
        if (buttonStatus & (1 << i)) {
#if DEBUG
          Serial.println("pressed.");
#endif

          //Record time that the button was pressed
          buttonTimer[i] = millis();

          //Mark the timer as "active"
          timerMask |= (1 << i);

          //Send associated keycode
          //(For D-Pad. Key sending functions for Circle and Dot buttons moved to timer delay to allow for dual press function)
          if (i < 4) {
            keyAction(i, true);
            buttonAction[i] = true;
          }
        }
        else {
          //Button triggered interrupt but isn't held... must've been released!
          Serial.println("released. ");
          keyAction(i, false);
          //"Deactivate" timer
          timerMask &= ~(1 << i);
#if DEBUG
          Serial.println("It was held for " + String(millis() - buttonTimer[i]) + "ms.");
#endif
        }
      }
      //How many buttons are held right now?
      if (buttonStatus & (1 << i)) {
        numPressed++;
      }
    }
#if DEBUG
    if (numPressed > 1) {
      Serial.println("There are " + String(numPressed) + " buttons being held.");
    }
    else {
      Serial.println();
    }
    Serial.println("TimerMask = " + String(timerMask, BIN));
#endif
  }
  timerActions();
  buttonActions();
  //Relay serial output from display driver if attached (v1.2 only)
  if (serialPassthrough) {
    while (Serial1.available()) {
      Serial.write(Serial1.read());
    }
    while (Serial.available()) {
      Serial1.write(Serial.read());
    }
  }
  else {
    while (Serial.available()) {
      char tempByte = Serial.read();
      switch (tempByte) {
        case 'r':
          portReset();
          break;
        case 'd':
          portDisable();
          break;
        case 'e':
          portEnable();
          break;
        case 'm':
          storageToggle();
          break;
        case 's':
          serialPassthrough = !serialPassthrough;
          break;
        case 'i':
          digitalWrite(DISP_RST, LOW);
          delay(10);
          digitalWrite(DISP_RST, HIGH);
          break;
         default:
          break;
      }
    }
    if(Serial1.available()){
      Serial1.flush();
    }
  }
}

void portReset() {
  digitalWrite(PORT_1, LOW);
  digitalWrite(PORT_2, LOW);
  portResetTimeout = millis() + portResetDuration;
  portResetting = true;
}

void storageToggle() {
  bool storageStatus = digitalRead(STORAGE);
  digitalWrite(STORAGE, !storageStatus);
  Serial.print("Mass storage turned ");
  if (storageStatus) {
    Serial.println("off.");
  }
  else {
    Serial.println("on.");
  }
}

void portDisable() {
  digitalWrite(PORT_1, LOW);
  digitalWrite(PORT_2, LOW);
#if DEBUG
  Serial.println("Ports Disabled");
#endif
}

void portEnable() {
  digitalWrite(PORT_1, HIGH);
  digitalWrite(PORT_2, HIGH);
#if DEBUG
  Serial.println("Ports Enabled");
#endif
}


//When called, this function either presses or releases a key from the keycode array
void keyAction(int key, bool pressing) {
  if (keyboardOutput) {
    if (pressing) {
      Keyboard.press(keycode[key]);
    }
    else {
      Keyboard.release(keycode[key]);
    }
  }
}

void timerActions() {
  if (timerMask) {                  //does a button have an active timer?
    long currentTime = millis();    //let's just read the time once. No need to keep consulting the hardware clock here
    if ((0b00010000 & timerMask) && !(0b00100000 & timerMask)) {    //Is button A held and button B isnt?
      if (currentTime - BUTTON_DELAY > buttonTimer[4]) {            //Has is been held longer than the time allocated to detect a dual-button press?
        keyAction(4, 1);                                 //Send the key!
        buttonAction[4] = true;
        timerMask &= (~(1 << 4));                                   //Kill the timer!
#if DEBUG
        Serial.println("TimerMask = " + String(timerMask, BIN));    //Tell the story!
#endif
      }
    }
    else {
      if ((0b00100000 & timerMask) && !(0b00010000 & timerMask)) {  //Same as above... yadda yadda yadda
        if (currentTime - BUTTON_DELAY > buttonTimer[5]) {
          keyAction(5, 1);
          buttonAction[5] = true;
          timerMask &= (~(1 << 5));
#if DEBUG
          Serial.println("TimerMask = " + String(timerMask, BIN));
#endif
        }
      }
      else {
        //Check if A and B have been held together for two seconds
        if ((0b00100000 & timerMask) && (0b00010000 & timerMask)) { //Are both buttons pressed? Separate comparisons because 0b00110000 & timerMask would evaluate to true for both OR one.
          long initiatedTime = currentTime - RESET_DELAY;                  //Let's count the dual press from when the first button press was detected
          if ((initiatedTime > buttonTimer[4]) && (initiatedTime > buttonTimer[5])) {
            portReset();
            timerMask &= (~(0b11 << 4));  //Kill timers for both A and B
#if DEBUG
            Serial.println("TimerMask = " + String(timerMask, BIN) + "Port Resetting");
#endif
          }
        }
      }
    }
  }

  if (portResetting && millis() > portResetTimeout) {
    digitalWrite(PORT_1, HIGH);
    digitalWrite(PORT_2, HIGH);
    portResetting = false;
#if DEBUG
    Serial.println("Port Reset complete");
#endif
  }
} //timerActions()

void buttonActions()
{
  for (int i = 0; i < 6; i++) {
    if (buttonAction[i]) {
      buttonAction[i] = false;
      ButtonFP[i]();
    }
  }
} //buttonActions()

void up() {
  //digitalWrite(STORAGE, !digitalRead(STORAGE));   //Toggle Storage Power
}

void down() {

}

void left() {
  //digitalWrite(PORT_1, !digitalRead(PORT_1));   //Toggle USB3 Port 1 Power
}

void right() {
  //digitalWrite(PORT_2, !digitalRead(PORT_2));   //Toggle USB3 Port 2 Power
}

void circle() {
/*
  if(serialPassthrough){
    serialPassthrough = false;
    Serial.println("Serial passthrough disabled");
  }
*/
}
 
void dot() {

}

// button() is an Arduino interrupt routine, called whenever
// the interrupt pin goes from HIGH to LOW.
void button()
{
  buttonPressed = true; // Set the buttonPressed flag to true
  // We can't do I2C communication in an Arduino ISR. The best
  // we can do is set a flag, to tell the loop() to check next
  // time through.
}

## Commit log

2020-08-25 added the schematic as a pdf for each project
2020-09-16 added firmware
    [ConfiguringApps.txt]
2020-09-16 added Example Sketches
    [NOVASTACK Adapter V0.2.brd]
2020-09-23 Update NorthStarHubTest.ino
    Corrected comments for left() and right() button functions as assigned for factory test protocol
2020-10-26 reassign INT to PE6
    [NorthStar_Hub V1.0.1 BOM.xls, NorthStar_Hub V1.0.1 PCB Parameters.txt, NorthStar_Hub V1.0.1.brd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]
2020-10-30 repo re-structured
    [Button V0.2.brd, Button V0.2.sch, ConfiguringApps.txt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]
2021-02-20 Update NorthStarButtons.ino
    added missing breaks to serial command char parser switch
    [NorthStarButtons.ino]
2021-04-07 Update NorthStarButtons.ino
    Commented out serial passthrough toggle accidentally left in circle() button function.
